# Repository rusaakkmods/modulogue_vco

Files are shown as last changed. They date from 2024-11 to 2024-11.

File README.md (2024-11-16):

### **Summary of Modular Synthesizer Project**

#### **Project Overview**
This modular synthesizer project involved designing and building multiple waveform generation and blending circuits, aimed at creating a versatile and adjustable synthesizer module. The primary goals were to implement various waveforms, include a noise source, and blend all the generated signals into a single output. The project also included specific modifications, such as fine-tuning, power supply design, and signal buffering to ensure stability and reliability.

#### **Key Components and Stages**

1. **Oscillator Core (Ramp Core)**
   - A ramp core oscillator was designed using a **TL072** operational amplifier as the integrator, along with a **2N3904** transistor and **CA3086** transistor array for current mirroring.
   - The integrator frequency is controlled by **RV1**, with an additional fine-tuning **trimmer (R36)**, allowing precise frequency adjustment.
   - **CD40106 Schmitt Trigger** inverters were used for signal buffering, ensuring the stability of the output signal.

2. **Waveform Generation and Blending**
   - The circuit generates several basic waveforms: **sawtooth, triangle, sine, and pulse**.
   - Each waveform output is blended with an adjustable amount of noise using **JFETs (2N5457)** as voltage-controlled amplifiers (VCAs).
   - The blend output of each waveform was further processed through a buffering stage using **TL072** operational amplifiers.

3. **Noise Source and Filtering**
   - A **white noise generator** was implemented using a **BC547** transistor, with the noise amplified by a **TL072** operational amplifier.
   - Adjustable filtering was added to shape the noise characteristics, providing both **high-pass** and **low-pass** controls, implemented with **RV7** and **RV6**.
   - The filtered noise was further buffered to ensure clean blending with the other waveforms.

4. **Signal Mixing**
   - The blended outputs of the sawtooth, triangle, sine, and pulse waveforms were mixed into a final output using a **TL072** operational amplifier configured as a summing amplifier.
   - **Mix Out** provides a composite audio signal with all waveforms mixed with noise, with individual blending for each waveform.

5. **Power Supply Design**
   - A **Eurorack power connector (J9)** was used for powering the module, providing **±12V, +5V, CV, and Gate** signals.
   - **Protection diodes (1N5819)** were added to each power line, followed by capacitors for decoupling and stability (±12V and +5V).
   - A **single power-on LED indicator** was added to the +5V line, indicating when the module is powered.

#### **Challenges and Improvements**
- **Thermal Coupling**: The **CA3086/3046** transistor array was used for better thermal coupling of the transistors, which helped reduce frequency drift and improved pitch stability.
- **Signal Buffering**: The use of **CD40106** Schmitt Trigger inverters for buffering was initially a concern due to their threshold nature. This was addressed by careful selection of the threshold voltage levels, ensuring proper signal integrity.
- **Component Selection**: The decision to use **TL072** for all operational amplifier needs was made due to its wide availability, cost-effectiveness, and adequate performance characteristics for audio signal processing.

#### **Outcome**
- A fully functional modular synthesizer module was designed, capable of generating sawtooth, triangle, sine, and pulse waveforms, each of which can be blended with an adjustable amount of noise.
- The project successfully addressed all the initial design goals, providing flexibility in waveform generation and blending, along with a stable power supply and efficient signal buffering.

This modular synthesizer is now ready for integration into a Eurorack system, providing unique sonic possibilities through its noise blending and waveform generation features.

### **Comprehensive Review of Synthesizer Schematics**

#### **Project Overview**
The goal of our project was to create a versatile analog synthesizer module capable of generating multiple waveform outputs, including sawtooth, triangle, sine, pulse, and noise. We also aimed for flexibility in signal blending, along with a reliable power section for consistent operation. The design uses commonly available components, ensuring it can be built with minimal specialized parts while providing a high level of functionality.

Below is a detailed review of the individual sections of the schematics, and how they align with our goals:

#### **1. Ramp Core Oscillator**
- **Schematic (01_ramp_core.png)**: The ramp core oscillator is at the heart of this synthesizer. It utilizes a **TL072 op-amp** to generate a stable ramp waveform, which serves as the basis for shaping other waveforms.
- **Components & Design Considerations**:
  - **CA3086/3046** transistor array forms a **current mirror**, which is key for controlling the ramp's linearity and stability.
  - **RV1 (100kΩ)** is used for frequency control, with **R36 (10kΩ)** added to ensure finer tuning.
  - The use of **Q2 (2N3904)** as a current sink and the **Schmitt trigger (CD40106)** for buffering ensures a sharp and well-defined ramp reset.
- **Conclusion**: This section effectively creates the ramp waveform with control over its frequency and reset characteristics. The fine-tuning and thermal coupling of transistors enhance pitch stability, meeting our goal of producing a precise core waveform.

#### **2. Triangle Wave Shaper**
- **Schematic (02_triangle_wave.png)**: The ramp waveform is shaped into a triangle wave using a **TL072** op-amp and a pair of **diodes (1N4148)**.
- **Symmetry Control**:
  - **RV4 (10kΩ)** allows for symmetry adjustments, ensuring a balanced triangle wave. Proper alignment of diodes helps achieve a linear slope on both halves of the triangle.
- **Conclusion**: The triangle wave is a fundamental waveform in many synthesis processes, and the use of a symmetry adjustment meets our goal of ensuring waveform accuracy.

#### **3. Sine Wave Shaper**
- **Schematic (03_sine_wave.png)**: The triangle waveform is converted into a sine wave through a feedback network using **capacitor C4** and **TL072**.
- **Shaping and Adjustment**:
  - The trimmer **RV2 (10kΩ)** is critical for reducing harmonic distortion and shaping the sine wave properly.
- **Conclusion**: The sine wave shaping circuit effectively smooths the triangle waveform, creating a sine with adjustable harmonic content. This fulfills our goal of generating a clean, adjustable sine output.

#### **4. Pulse Wave Shaper**
- **Schematic (04_pulse_wave.png)**: The **TL072 (U4B)** op-amp shapes the input from the triangle waveform and LFO into a pulse waveform.
- **Pulse Width Control**:
  - **RV5 (10kΩ)** allows manual control of the pulse width, while the **LFO** input modulates the pulse width, adding versatility for different modulation scenarios.
- **Conclusion**: The pulse width modulation capability, along with manual control, provides the desired flexibility in sound design, meeting our project objectives for waveform variety.

#### **5. Noise Generator**
- **Schematic (05_noise_generator_v2.png)**: Noise is generated using a **CA3086/3046 transistor** and amplified with a **TL072 (U5A)**.
- **Filtering**:
  - **RV7** and **RV8** are used to control the high-pass filter characteristics, allowing adjustments in the coloration of the noise output.
- **Conclusion**: Noise generation with adjustable filtering is useful for creating diverse sound textures, aligning well with our goal of a versatile noise section.

#### **6. Waveform Blending and Summing**
- **Schematic (06_mixed_out.png)**: Each waveform output is blended using a **summing amplifier (TL072, U10B)**.
- **Mixing Control**:
  - Equal resistances (**100kΩ**) for each input ensure that all waveforms are summed evenly, providing a balanced mixed output.
- **Conclusion**: This blending stage achieves the goal of providing a single output that contains a mix of all generated waveforms, offering a comprehensive signal suitable for various applications.

#### **7. Power Supply and Distribution**
- **Schematic (07_power_connector.png)**: The power section delivers **+12V, -12V, and +5V** to the different parts of the circuit.
- **Power Integrity**:
  - **Diodes (1N5819)** protect against reverse polarity, and capacitors ensure proper decoupling.
  - The addition of an LED indicator for the **+5V** line serves as a power-on visual indicator.
- **Conclusion**: The power section is robust, ensuring stable operation across the synthesizer. Proper decoupling and visual status indication align with the goal of reliability.

#### **8. Output Connections**
- **Schematic (08_outputs.png)**: Each generated waveform, including the mixed output, is connected to individual output jacks.
- **Labelling and Accessibility**:
  - Proper labeling of outputs ensures that each waveform can be accessed easily, making the synthesizer user-friendly.
- **Conclusion**: The output interface meets our objective of making all waveforms accessible for external use, fulfilling the goal of usability.

### **Overall Assessment**
The project successfully meets the outlined objectives:
- **Versatility**: The synthesizer offers a wide range of waveforms—sawtooth, triangle, sine, pulse, and noise—each with adjustable parameters, providing a rich palette for sound design.
- **Stability and Control**: The use of **thermal coupling**, **fine-tuning trimmers**, and **proper filtering** ensures the oscillator remains stable, while the power section guarantees reliable operation.
- **User-Friendly Design**: The interface, including labeled outputs and the power-on indicator, makes the synthesizer easy to operate.

Overall, the design is well-executed, with each section effectively contributing to the synthesizer's versatility and reliability. The schematics illustrate a thoughtful and methodical approach to achieving a high-quality analog synthesizer module.

#### **Complete Bill of Materials (BOM)**

| No | Reference | Value | Qty |
| -- | --- | --- | --- |
| 1  | C1 | 22nF | 1 |
| 2  | C2, C3, C5, C6, C10, C11, C12, C17, C18, C19, C20, C21, C22, C23, C24, C25, C26, C27, C28, C29, C32 | 100nF | 21  |
| 3  | C4, C7 | 10pF ~ 33pF | 2 |
| 4  | C8, C13, C14, C15, C16 | 10uF | 5 |
| 5  | C9 | 10nF | 1 |
| 6  | C30, C31, C33 | 47uF | 3 |
| 7  | D1, D2 | 1N4148 | 2 |
| 8  | D3, D4, D5, D6 | 1N4148 | 4 |
| 9  | D7, D8, D9 | 1N5819 | 3 |
| 10 | D10 | POWER ON | 1 |
| 11 | J1 | SAWTOOTH | 1 |
| 12 | J2 | TRIANGLE | 1 |
| 13 | J3 | SINE | 1 |
| 14 | J4 | PULSE | 1 |
| 15 | J5 | MIX OUT | 1 |
| 16 | J6 | NOISE | 1 |
| 17 | J7 | HP NOISE | 1 |
| 18 | J9 | POWER | 1 |
| 19 | J10 | CV IN | 1 |
| 20 | Q2 | 2N3904 | 1 |
| 21 | Q3, Q4, Q5, Q6 | 2N5457 | 4 |
| 22 | R1, R15, R20, R21, R22, R23, R24, R25, R26, R27, R28, R29, R30, R31, R32, R33, R34, RV1 | 100K | 18  |
| 23 | R2, R6, R9, R10, R11, R12, R18, R19, R36, RV2, RV4, RV5 | 10K | 12  |
| 24 | R3, R4, R5, R7, R8, R13, R35 | 1K | 7 |
| 25 | R14, R16 | 1M | 2 |
| 26 | R17 | 470K | 1 |
| 27 | RV3, RV6, RV7, RV8 | 50K | 4 |
| 28 | U1, U4, U5, U6, U7, U8, U9, U10 | TL072 | 8 |
| 29 | U2 | CD40106 | 1 |
| 30 | U3 | CA3086/3046 | 1 |

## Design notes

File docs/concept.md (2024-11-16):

Here's a complete schematic and routing guide for your VCO module, using the **CA3086** transistor array. This design includes **sawtooth, triangle, sine, pulse, and noise** waveforms, along with an updated **Bill of Materials (BOM)**. I'll provide a clear description of each section, as well as connections to guide you through the process.

### **Schematic Overview**

The VCO is divided into the following stages:

1. **Sawtooth Core Oscillator (Ramp Core) with CA3086**
2. **Triangle Wave Shaper**
3. **Sine Wave Shaper**
4. **Pulse Wave with PWM Control**
5. **Noise Generator**

#### **1. Sawtooth Core Oscillator (Ramp Core with CA3086)**

**Components**:
- **Op-Amp (U1)**: TL072 or LM13700 for the integrator.
- **Capacitor (C1)**: 22nF to 100nF (sets frequency range).
- **Resistor (R1)**: 100kΩ.
- **Transistor Array (Q1, Q2 - CA3086)**: Used for the exponential converter.
- **Schmitt Trigger (IC1)**: CD40106 for reset control.
- **NPN Transistor (Q3 - Reset)**: 2N3904.
- **Current Limiting Resistor (R2)**: 10kΩ.
- **Frequency Control Potentiometer (VR2)**: 100kΩ for manual frequency adjustment.

**Connections**:
- **Integrator Op-Amp (U1)**:
  - **Inverting Input (-)**: Connect **R1** (100kΩ) between the **inverting input** and the **collector of Q1** (CA3086).
  - **Non-Inverting Input (+)**: Connect to **ground**.
  - **Capacitor C1**: Connect between the **output of U1** and the **inverting input (-)**.
  - **Frequency Control Potentiometer (VR2)**: Connect one end of **VR2** to **ground** and the other end to the **junction of C1 and U1**. The wiper of **VR2** should connect to the **inverting input** of **U1**. Adjusting **VR2** will change the effective resistance in the circuit, allowing you to control the oscillator frequency.
- **CA3086 Transistor Array**:
  - **Base of Q1**: Connect to the **1V/octave CV input**.
  - **Emitters of Q1 and Q2**: Tie together and connect to **ground** via a **small resistor (R3 - 1kΩ)**.
  - **Collector of Q1**: Connect to **R1**, which then goes to **U1** inverting input.
- **Schmitt Trigger (IC1 - CD40106)**:
  - **Input (Pin 1)**: Connect to the **output of U1** (sawtooth waveform).
  - **Output (Pin 2)**: Connect to the **base of Q3** via a **current-limiting resistor (R2 - 10kΩ)**.
- **Reset Transistor (Q3 - 2N3904)**:
  - **Collector**: Connect to the **junction of C1 and U1**.
  - **Emitter**: Connect to **ground**.

#### **2. Triangle Wave Shaper**

**Components**:
- **Op-Amp (U2)**: TL072.
- **Resistor Divider (R4, R5)**: 10kΩ each to adjust symmetry.

**Connections**:
- **Sawtooth Output to Triangle Shaper**:
  - Connect the **sawtooth output from U1** to the **inverting input of U2** through **R4** (10kΩ).
  - **Non-Inverting Input** of **U2** should be connected to **ground**.
- **Triangle Wave Output**:
  - The **output of U2** will generate a **triangle wave** by inverting and folding the sawtooth.

#### **3. Sine Wave Shaper**

**Components**:
- **Op-Amp (U3)**: TL072.
- **Diodes (D1, D2)**: 1N4148 for wave shaping.

**Connections**:
- **Triangle Wave Input**:
  - Feed the **triangle wave output from U2** to the **input of U3**.
- **Shaper Circuit**:
  - Connect **D1 and D2** across the **feedback path** of **U3** to round the triangle wave into a sine.
- **Sine Wave Output**:
  - The **output of U3** will be the **sine wave**.

#### **4. Pulse Wave with PWM Control**

**Components**:
- **Schmitt Trigger (IC1 - Gate 2)**: CD40106.
- **PWM Control Potentiometer (VR1)**: 100kΩ.

**Connections**:
- **Sawtooth to Schmitt Trigger**:
  - Connect the **sawtooth output** from **U1** to the **input of another gate on IC1** (e.g., Pin 3).
- **PWM Control**:
  - Use **VR1** to provide an adjustable **threshold voltage** to the **input of the Schmitt Trigger**.
- **Pulse Wave Output**:
  - The **output of the Schmitt Trigger gate** will provide the **pulse wave** with adjustable PWM.

#### **5. Noise Generator**

**Components**:
- **NPN Transistor (Q4)**: 2N3904 for noise generation.
- **Amplifier Op-Amp (U4)**: TL072.
- **Collector Resistor (R6)**: 100kΩ.
- **Capacitor (C2)**: 100nF for noise filtering.

**Connections**:
- **Noise Source**:
  - Use **Q4** with its **collector-base junction reverse biased** to generate **white noise**.
- **Amplification**:
  - Feed the **noise output from Q4** to **U4** configured as an amplifier.
  - The **output of U4** will be the **noise signal**.

### **Bill of Materials (BOM)**

| Part Description | Reference | Value | Suggested Part Number  | Quantity |
|---|---|---|---|---|
| Op-Amp | U1, U2, U3, U4 | TL072 | TL072CN | 4 |
| Capacitor (Integrator) | C1 | 22nF | Ceramic or Film | 1 |
| Resistor (Integrator) | R1 | 100kΩ | 1/4W, 1% Tolerance | 1 |
| Transistor Array | Q1, Q2 | CA3086 | CA3086 | 1 |
| Small Resistor (Thermal Stability) | R3 | 1kΩ | 1/4W, 1% Tolerance | 1 |
| Schmitt Trigger | IC1 | CD40106 | CD40106BE | 1 |
| NPN Transistor (Reset) | Q3 | 2N3904 | 2N3904 | 1 |
| Current Limiting Resistor  | R2 | 10kΩ | 1/4W, 1% Tolerance | 1 |
| Resistor Divider | R4, R5 | 10kΩ each | 1/4W, 1% Tolerance | 2 |
| Diodes for Sine Shaper | D1, D2 | 1N4148 | 1N4148 | 2 |
| Potentiometer (PWM Control)| VR1 | 100kΩ | Linear Taper | 1 |
| Potentiometer (Frequency Control) | VR2 | 100kΩ | Linear Taper | 1 |
| NPN Transistor (Noise Source) | Q4 | 2N3904 | 2N3904 | 1 |
| Resistor (Collector Resistor) | R6 | 100kΩ | 1/4W, 1% Tolerance | 1 |
| Capacitor (Noise Filtering)| C2 | 100nF | Ceramic | 1 |
| Decoupling Capacitors | C3, C4, C5  | 100nF | Ceramic | 3 |

### **Power Supply and Layout Tips**
- **Power Supply**: Use the **Eurorack standard power supply** of **±12V** for proper operation of op-amps and CD40106.
- **Decoupling**: Place **100nF capacitors** near each IC's power pins to reduce noise.
- **Grounding**: Use **star grounding** to avoid ground loops.
- **Thermal Considerations**: Place **CA3086** transistors close together for consistent thermal tracking.

### **Summary**
This design uses the **CA3086** transistor array for improved matching and thermal stability, making it an excellent choice for your VCO project. The guide includes all necessary components, connections, and routing tips to create a reliable and stable oscillator for your modular synthesizer.

### **Alternatives to CA3086 Transistor Array**

If you're looking for alternatives to the **CA3086** transistor array for use in applications like exponential converters in synthesizer circuits, here are some viable options:

#### **1. LM3046**
- **LM3046** is a direct replacement for the **CA3086**. It also contains **five NPN transistors** in a single package.
- It features **similar specifications** and offers excellent **matching** and **thermal tracking**, making it a drop-in alternative.

#### **2. CA3046**
- **CA3046** is another option that contains **five NPN transistors** like the **CA3086**.
- This array offers **matched transistors** suitable for differential pairs and analog applications where thermal tracking is crucial.

#### **3. MAT12 (Analog Devices)**
- The **MAT12** is a **dual NPN matched transistor** from **Analog Devices**, designed for precision analog circuits.
- It provides **excellent thermal matching**, much better than discrete transistors, making it a suitable but more expensive alternative.
- The **MAT12** is known for its **low noise** and **excellent gain matching**, making it ideal for high-performance VCO designs.

#### **4. SSM2212**
- **SSM2212** is another **dual matched NPN transistor** designed for precision.
- Manufactured by **Analog Devices**, this component is well-suited for **exponential converters** due to its **closely matched gain** and **temperature coefficient**.

#### **5. Discrete Matched Transistor Pairs (e.g., BC547)**
- Another approach is to manually match **discrete transistors** like **BC547**.
- This requires careful measurement to ensure similar **gain (HFE)** and **base-emitter voltage (V_BE)**.
- While this method is more time-consuming, it is cost-effective if the **CA3086** or similar arrays are not readily available.

#### **6. THAT300 (THAT Corporation)**
- The **THAT300** is a **quad NPN transistor array** specifically designed for analog precision applications.
- It has **four transistors** that are matched and thermally coupled on the same die.
- This component provides excellent **matching** and is often used in high-end analog synthesizer designs.

### **Summary of Alternatives**
- **Direct Replacements**: **LM3046**, **CA3046**.
- **High Precision**: **MAT12**, **SSM2212**, **THAT300**.
- **Cost-Effective Option**: **Manually matched discrete transistors** like **BC547**.

The best alternative will depend on your specific requirements—if you're looking for cost-effectiveness, manually matched **BC547** transistors may be suitable, while the **LM3046** or **CA3046** can be direct substitutes with similar characteristics to the **CA3086**. For higher precision, **MAT12** or **THAT300** would be ideal, especially in designs where temperature stability and minimal drift are critical.

### **CA3086 vs CA3046**

The **CA3086** and **CA3046** are both transistor arrays containing **five NPN transistors** and are commonly used in analog applications where matched transistors are required. Here is a comparison to help you understand the differences and similarities between the two:

#### **Similarities**
1. **Transistor Count**: Both **CA3086** and **CA3046** contain **five NPN transistors** on a single chip.
2. **Monolithic Design**: The transistors are fabricated on the same die, ensuring good **matching** and **thermal tracking**.
3. **Application Use**: Both can be used in **exponential converters**, **differential pairs**, or other analog circuits where matched transistors are required.
4. **Pin Configuration**: The **pinout** of the CA3086 and CA3046 is identical, making them interchangeable in most circuit designs.

#### **Differences**
1. **Voltage Ratings**:
   - The **CA3046** has a higher **collector-emitter voltage rating** compared to the **CA3086**.
   - **CA3046** can handle a **maximum collector-emitter voltage (V_CE)** of **20V**, while **CA3086** typically has a lower voltage rating of **15V**.
2. **Temperature Range**:
   - The **CA3046** is rated for **wider temperature ranges**, making it more suitable for industrial applications where the operating environment may be harsher.
   - The **CA3086** is more commonly used in consumer electronics or in environments with more controlled temperatures.
3. **Availability**:
   - The **CA3046** is generally easier to find compared to the **CA3086**, which might be less available in the market due to its older technology.

#### **Which One to Use?**
- **CA3086**: Suitable for projects where **voltage ratings** are not a concern, and operating in typical room temperature conditions. It is a good option for hobbyist projects or legacy circuits where the **CA3086** was originally used.
- **CA3046**: Recommended for designs that require **higher voltage ratings** or need to operate in **wider temperature ranges**. It is a more robust option for applications where reliability over a range of conditions is critical.

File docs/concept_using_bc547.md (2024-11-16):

Here's a complete schematic and routing guide for your VCO module, using **matched BC547 transistors** instead of the **CA3086** transistor array. This design includes **sawtooth, triangle, sine, pulse, and noise** waveforms, along with an updated **Bill of Materials (BOM)**. I'll provide a clear description of each section, as well as connections to guide you through the process.

### **Schematic Overview**

The VCO is divided into the following stages:

1. **Sawtooth Core Oscillator (Ramp Core with Matched BC547 Transistors)**
2. **Triangle Wave Shaper**
3. **Sine Wave Shaper**
4. **Pulse Wave with PWM Control**
5. **Noise Generator**

#### **1. Sawtooth Core Oscillator (Ramp Core with Matched BC547 Transistors)**

**Components**:
- **Op-Amp (U1)**: TL072 or LM13700 for the integrator.
- **Capacitor (C1)**: 22nF to 100nF (sets frequency range).
- **Resistor (R1)**: 100kΩ.
- **Matched Transistors (Q1, Q2 - BC547)**: Used for the exponential converter.
- **Schmitt Trigger (IC1)**: CD40106 for reset control.
- **NPN Transistor (Q3 - Reset)**: 2N3904.
- **Current Limiting Resistor (R2)**: 10kΩ.
- **Frequency Control Potentiometer (VR2)**: 100kΩ for manual frequency adjustment.

**Connections**:
- **Integrator Op-Amp (U1)**:
  - **Inverting Input (-)**: Connect **R1** (100kΩ) between the **inverting input** and the **collector of Q1** (BC547).
  - **Non-Inverting Input (+)**: Connect to **ground**.
  - **Capacitor C1**: Connect between the **output of U1** and the **inverting input (-)**.
  - **Frequency Control Potentiometer (VR2)**: Connect one end of **VR2** to **ground** and the other end to the **junction of C1 and U1**. The wiper of **VR2** should connect to the **inverting input** of **U1**. Adjusting **VR2** will change the effective resistance in the circuit, allowing you to control the oscillator frequency.
- **Matched Transistors (Q1, Q2 - BC547)**:
  - **Base of Q1**: Connect to the **1V/octave CV input**.
  - **Emitters of Q1 and Q2**: Tie together and connect to **ground** via a **small resistor (R3 - 1kΩ)**.
  - **Collector of Q1**: Connect to **R1**, which then goes to **U1** inverting input.
- **Schmitt Trigger (IC1 - CD40106)**:
  - **Input (Pin 1)**: Connect to the **output of U1** (sawtooth waveform).
  - **Output (Pin 2)**: Connect to the **base of Q3** via a **current-limiting resistor (R2 - 10kΩ)**.
- **Reset Transistor (Q3 - 2N3904)**:
  - **Collector**: Connect to the **junction of C1 and U1**.
  - **Emitter**: Connect to **ground**.

#### **2. Triangle Wave Shaper**

**Components**:
- **Op-Amp (U2)**: TL072.
- **Resistor Divider (R4, R5)**: 10kΩ each to adjust symmetry.

**Connections**:
- **Sawtooth Output to Triangle Shaper**:
  - Connect the **sawtooth output from U1** to the **inverting input of U2** through **R4** (10kΩ).
  - **Non-Inverting Input** of **U2** should be connected to **ground**.
- **Triangle Wave Output**:
  - The **output of U2** will generate a **triangle wave** by inverting and folding the sawtooth.

#### **3. Sine Wave Shaper**

**Components**:
- **Op-Amp (U3)**: TL072.
- **Diodes (D1, D2)**: 1N4148 for wave shaping.

**Connections**:
- **Triangle Wave Input**:
  - Feed the **triangle wave output from U2** to the **input of U3**.
- **Shaper Circuit**:
  - Connect **D1 and D2** across the **feedback path** of **U3** to round the triangle wave into a sine.
- **Sine Wave Output**:
  - The **output of U3** will be the **sine wave**.

#### **4. Pulse Wave with PWM Control**

**Components**:
- **Schmitt Trigger (IC1 - Gate 2)**: CD40106.
- **PWM Control Potentiometer (VR1)**: 100kΩ.

**Connections**:
- **Sawtooth to Schmitt Trigger**:
  - Connect the **sawtooth output** from **U1** to the **input of another gate on IC1** (e.g., Pin 3).
- **PWM Control**:
  - Use **VR1** to provide an adjustable **threshold voltage** to the **input of the Schmitt Trigger**.
- **Pulse Wave Output**:
  - The **output of the Schmitt Trigger gate** will provide the **pulse wave** with adjustable PWM.

#### **5. Noise Generator**

**Components**:
- **NPN Transistor (Q4)**: 2N3904 for noise generation.
- **Amplifier Op-Amp (U4)**: TL072.
- **Collector Resistor (R6)**: 100kΩ.
- **Capacitor (C2)**: 100nF for noise filtering.

**Connections**:
- **Noise Source**:
  - Use **Q4** with its **collector-base junction reverse biased** to generate **white noise**.
- **Amplification**:
  - Feed the **noise output from Q4** to **U4** configured as an amplifier.
  - The **output of U4** will be the **noise signal**.

### **Bill of Materials (BOM)**

| Part Description | Reference | Value | Suggested Part Number  | Quantity |
|---|---|---|---|---|
| Op-Amp | U1, U2, U3, U4 | TL072 | TL072CN | 4 |
| Capacitor (Integrator) | C1 | 22nF | Ceramic or Film | 1 |
| Resistor (Integrator) | R1 | 100kΩ | 1/4W, 1% Tolerance | 1 |
| Matched Transistors | Q1, Q2 | BC547 | Hand-matched BC547 | 2 |
| Small Resistor (Thermal Stability) | R3 | 1kΩ | 1/4W, 1% Tolerance | 1 |
| Schmitt Trigger | IC1 | CD40106 | CD40106BE | 1 |
| NPN Transistor (Reset) | Q3 | 2N3904 | 2N3904 | 1 |
| Current Limiting Resistor  | R2 | 10kΩ | 1/4W, 1% Tolerance | 1 |
| Resistor Divider | R4, R5 | 10kΩ each | 1/4W, 1% Tolerance | 2 |
| Diodes for Sine Shaper | D1, D2 | 1N4148 | 1N4148 | 2 |
| Potentiometer (PWM Control)| VR1 | 100kΩ | Linear Taper | 1 |
| Potentiometer (Frequency Control) | VR2 | 100kΩ | Linear Taper | 1 |
| NPN Transistor (Noise Source) | Q4 | 2N3904 | 2N3904 | 1 |
| Resistor (Collector Resistor) | R6 | 100kΩ | 1/4W, 1% Tolerance | 1 |
| Capacitor (Noise Filtering)| C2 | 100nF | Ceramic | 1 |
| Decoupling Capacitors | C3, C4, C5  | 100nF | Ceramic | 3 |

### **Power Supply and Layout Tips**
- **Power Supply**: Use the **Eurorack standard power supply** of **±12V** for proper operation of op-amps and CD40106.
- **Decoupling**: Place **100nF capacitors** near each IC's power pins to reduce noise.
- **Grounding**: Use **star grounding** to avoid ground loops.
- **Thermal Considerations**: Place **Q1 and Q2** (BC547) close together and consider using thermal compound or adhesive to improve thermal tracking.

### **Summary**
This design uses **matched BC547 transistors** for the exponential converter instead of the **CA3086** array. Careful matching of the transistors is important to achieve good temperature stability. The guide includes all necessary components, connections, and routing tips to create a reliable and stable oscillator for your modular synthesizer.

### **Guide to Manual Matching of Transistors**

Manual matching of transistors is an important process for circuits like **exponential converters** in VCOs, where precise performance and temperature stability are crucial. Here's a step-by-step guide to manually match transistors, particularly for **BC547** transistors.

#### **Goal of Matching Transistors**
For circuits like **exponential converters** in a VCO, it is important to match transistors for the following characteristics:
1. **Current Gain (HFE)** - The ratio of collector current to base current.
2. **Base-Emitter Voltage (V_BE)** - The voltage drop from base to emitter when conducting.

Closely matching these parameters helps improve the **accuracy** and **temperature stability** of your circuit.

#### **Equipment Needed**
1. **Multimeter with HFE Measurement** (preferable).
2. **Breadboard and Power Supply** (optional if you prefer building a test circuit).
3. **Test Circuit Components** - Resistors, battery, wires (optional if you need to measure with a test setup).

#### **Step-by-Step Guide to Manually Match Transistors**

##### **Method 1: Using a Multimeter with HFE Measurement**

1. **Set the Multimeter to HFE Mode**:
   - Most multimeters have a setting for measuring the **HFE** of transistors. Set your multimeter to this mode.

2. **Identify the Pins**:
   - The **BC547** is a standard NPN transistor with the pinout: **Collector (C)**, **Base (B)**, **Emitter (E)**.
   - Identify these pins on the transistor using the datasheet or reference image (typically, if looking at the flat face of the transistor, from left to right: **C**, **B**, **E**).

3. **Insert the Transistor**:
   - Insert the **collector, base, and emitter** pins of the transistor into the corresponding slots in the **HFE socket** of the multimeter (often labeled for NPN and PNP transistors).

4. **Record the HFE Value**:
   - Read the **HFE** value displayed on the multimeter and note it down.
   - Repeat this process for all the transistors you want to match, and write down each **HFE** value.

5. **Match Transistors**:
   - Compare the **HFE values** of all the transistors.
   - Find two transistors that have nearly identical **HFE values**. Ideally, they should be within **5%** of each other for good matching in a VCO application.

##### **Method 2: Using a Test Circuit on a Breadboard**

If your multimeter does not have an **HFE measurement mode**, you can use a simple test circuit to measure **V_BE** and **HFE**.

1. **Test Circuit Setup**:
   - Use a **breadboard** to set up a simple circuit to measure **HFE** and **V_BE**.
   - You’ll need:
     - **Power Supply** (e.g., a **9V battery** or a **DC power supply** set to 9-12V).
     - **Resistor** (1kΩ and 10kΩ).

2. **Circuit Description**:
   - Connect a **1kΩ resistor** between the **base** and the **positive supply**.
   - Connect a **10kΩ resistor** between the **collector** and the **positive supply**.
   - Connect the **emitter** to **ground**.

3. **Measure Collector Current (I_C)**:
   - Measure the **voltage across the 10kΩ collector resistor** using the multimeter.
   - **Calculate the collector current (I_C)** using **Ohm’s Law**: \( I_C = 
rac{V_R}{R} \), where \( V_R \) is the voltage across the resistor and \( R \) is the resistor value (10kΩ).
   
4. **Calculate Base Current (I_B)**:
   - Measure the **voltage across the 1kΩ base resistor**.
   - **Calculate the base current (I_B)** similarly: \( I_B = 
rac{V_R}{R} \), where \( V_R \) is the voltage across the 1kΩ resistor.

5. **Calculate HFE**:
   - Use the formula: \( HFE = 
rac{I_C}{I_B} \).
   - Record this value for each transistor.

6. **Measure V_BE**:
   - Measure the **voltage drop between the base and emitter (V_BE)**.
   - Note that **V_BE** should ideally be close, preferably within **5mV** for well-matched transistors.

7. **Select Matched Pairs**:
   - Compare the **HFE** values and **V_BE** values of all transistors.
   - Select transistors that have similar **HFE** and **V_BE** values.

#### **Tips for Manual Matching**

1. **Thermal Matching**:
   - Perform measurements under consistent temperature conditions. Small changes in temperature can affect **HFE** and **V_BE** significantly.
   - If possible, keep the transistors close together or even attach them with a thermally conductive adhesive when assembling the final circuit to minimize differences due to temperature variations.

2. **Batch Measurement**:
   - It’s a good idea to buy more transistors than needed and measure them all to find the closest match.
   - Transistors from the **same batch** are more likely to have similar characteristics due to the consistency of manufacturing.

3. **Target Matching Accuracy**:
   - For most analog synthesizer VCO applications, aim for **matching within 5%** for **HFE** and **within 5-10mV** for **V_BE**.
   - Better matching will result in **more accurate pitch tracking** and **less drift** with temperature changes.

#### **Summary**
- Use a **multimeter with HFE measurement** if available—this is the easiest and quickest way to match transistors.
- Alternatively, build a **test circuit** to measure **HFE** and **V_BE** if a dedicated HFE meter is not available.
- Look for **matched HFE and V_BE** values to ensure stability, especially for the **exponential converter** stage in a **VCO**.

Using well-matched transistors will provide the **temperature stability** and **precision** necessary for reliable musical tuning and pitch tracking in your synthesizer project.

### **Methods to Improve Thermal Tracking for BC547 Transistors**

Thermal tracking is critical in circuits like **exponential converters** used in **VCOs** to ensure consistent performance and minimal pitch drift. For **BC547 transistors**, here are effective methods to improve thermal tracking:

#### **1. Thermal Adhesive Compound**
- Apply a **thermal adhesive compound** between the two matched transistors (e.g., **Q1 and Q2** in your VCO circuit).
- This ensures that both transistors are in **direct thermal contact**, allowing them to heat up and cool down at the same rate.
- By maintaining a similar temperature, the **gain (HFE)** and **V_BE** remain more consistent, improving stability.

#### **2. Heat Shrink Tubing**
- Use a piece of **heat shrink tubing** to encase both transistors together.
- This method holds the transistors in tight physical contact, improving thermal equilibrium between them.
- The heat shrink tubing helps them share heat effectively, reducing any thermal gradient that might cause drift.

#### **3. Copper Foil or Heatsink**
- Wrap both transistors with **copper foil tape** to increase their thermal conductivity.
- Copper is highly thermally conductive, and wrapping it around the transistors will help distribute heat evenly between them.
- Alternatively, use a small **metal heatsink** that is in contact with both transistors to stabilize their temperature.

#### **4. Mounting on the Same PCB Pad**
- Place both transistors on the same **thermal pad** or closely spaced **PCB area**.
- The shared **copper pad** helps to maintain an even temperature between the transistors, as it acts as a heat spreader.
- Make sure to avoid excessive spacing between the transistors, as proximity is key for effective thermal coupling.

#### **Summary**
- **Thermal Adhesive Compound** and **heat shrink tubing** are the simplest methods for improving thermal tracking of **BC547 transistors**.
- Using **copper foil tape** or a **heatsink** further enhances thermal contact and helps maintain temperature consistency.
- **PCB layout considerations**, such as mounting both transistors on the same pad, also play a crucial role in ensuring they track each other's temperature closely.

These methods will help minimize temperature-induced variations in the **exponential converter** circuit, leading to improved stability and pitch accuracy for your VCO.

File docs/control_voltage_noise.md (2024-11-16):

### **Voltage-Controlled Noise Blending Using Waveform Signal**

You can achieve voltage-controlled noise blending by using the waveform signal itself to dynamically control the noise level. This approach creates a more dynamic and interesting effect, where the noise level changes in sync with the generated waveform, resulting in unique sonic characteristics.

#### **Solution Overview**

1. **Using Waveform Voltage as Control Signal**:
   - You can use the voltage from each waveform output (sawtooth, triangle, sine, pulse) to control the amplitude of the noise through a **Voltage-Controlled Amplifier (VCA)** or other modulation mechanisms.
   - The waveform acts as the **modulation source**, and the noise level changes accordingly with the waveform's voltage.

2. **Implementation Using VCA**:
   - Use a **Voltage-Controlled Amplifier (VCA)** to adjust the amplitude of the noise signal based on the waveform voltage.
   - The VCA will allow the noise level to be controlled dynamically. When the waveform voltage is high, the noise level will be high; when the waveform voltage is low, the noise level will decrease.

3. **Using a JFET (2N5457) as a VCA**:
   - A **JFET (2N5457)** can be used as a variable resistor in a VCA configuration.
   - Connect the noise signal to the **drain** of the JFET, and use the **gate** to receive the waveform voltage. This will control the effective resistance and hence modulate the noise output level.

4. **Envelope Follower Approach**:
   - Another way to control the noise level is to use an **envelope follower** to generate a control voltage from the waveform. The control voltage can then be used to drive a VCA or other modulation elements.
   - This approach allows for a more stable, smoothed-out control over the noise level, based on the overall amplitude of the waveform.

#### **Step-by-Step Implementation**

1. **Waveform as Control Signal**:
   - Take the output from each waveform generator (sawtooth, triangle, sine, pulse).
   - Use a **diode and capacitor** to create an **envelope follower**, which generates a control voltage proportional to the waveform amplitude.

2. **VCA for Noise Control**:
   - Use a **JFET-based VCA (2N5457)** to control the amplitude of the noise signal.
   - Connect the noise signal to the **drain** of the JFET, and the **source** to the output. The **gate** will receive the control voltage derived from the waveform, modulating the effective resistance of the JFET.

3. **Summing the Blended Output**:
   - After controlling the noise amplitude, use the existing **op-amp summing mixer** configuration to blend the noise signal into the respective waveform output.
   - This ensures that the final output contains the waveform with the dynamically controlled noise level.

#### **Advantages of Voltage-Controlled Noise Blending**

1. **Dynamic Noise Control**: The noise level changes dynamically based on the waveform amplitude, creating interesting sound effects and adding a dynamic layer to the synthesis.
2. **Unique Modulation Effects**: Different waveforms can be used to modulate the noise, resulting in unique noise effects that change with the waveform's shape and frequency.
3. **Simpler Implementation**: Using a JFET (2N5457) as a VCA provides a relatively simple and cost-effective method for achieving voltage-controlled noise modulation.

#### **Considerations**

- **Complexity**: Adding VCAs or using a JFET introduces more components and complexity to the circuit, but it provides significant control over the noise level.
- **Level Scaling**: The waveform voltage should be properly scaled to match the control requirements of the VCA or JFET. This may require additional circuitry, such as **op-amp buffers** or **level shifters**.

#### **Bill of Materials (BOM) Update**

| Part Description | Reference | Value | Suggested Part Number | Quantity |
|---|---|---|---|---|
| JFET | Q2 | 2N5457 | 2N5457 | 4 |
| Diode for Envelope Follower | D1, D2, D3, D4  | 1N4148 | 1N4148 | 4 |
| Capacitor for Envelope Follower | C14, C15, C16, C17 | 10μF | Electrolytic | 4 |
| Resistors for VCA | R26, R27, R28, R29 | 100kΩ | 1/4W, 1% Tolerance | 4 |
| Summing Op-Amp | U7A, U7B | TL072 | TL072CN | 2 |

This BOM update includes additional components for implementing voltage-controlled noise blending, including JFETs (2N5457) for the VCAs, diodes, and capacitors for the envelope follower, as well as additional resistors. Let me know if you need further clarification or additional assistance!

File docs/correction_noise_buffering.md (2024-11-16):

### **Detailed Schematic Routing for Noise Buffering Using TL072 and Waveform Mixing**

#### **Noise Buffering Using TL072**

1. **Buffered Noise Amplification**:
   - Start with the **filtered noise signal** output from the **filtered noise amplification stage**. This output comes from **pin 7** of **U5B (TL072)**.

2. **Connect to Buffer Op-Amp**:
   - Connect the output from **U5B (pin 7)** to the **non-inverting input (+)** of the buffer op-amp, which is **U6A (TL072)**.
   - Use a direct wire to connect **U5B (pin 7)** to **U6A (pin 3)**. This connection carries the filtered noise signal into the next op-amp stage.

3. **Voltage Follower Configuration**:
   - To configure **U6A (TL072)** as a **voltage follower**:
     - Connect the **output of U6A (pin 1)** directly to its **inverting input (-)**, which is **pin 2**.
     - This is done using a short wire to create a direct feedback loop, ensuring the op-amp operates as a unity gain buffer.
   - In this configuration, the output follows the input exactly, maintaining the analog characteristics of the signal.

4. **Buffered Noise Output**:
   - The buffered noise output is now taken from **pin 1** of **U6A**.
   - This output can be routed to the next stages, such as the **JFET-based VCAs** that blend the noise with the various waveforms.

5. **Power Connections**:
   - **VCC (+12V)**: Connect **pin 8** of **U6A** to **+12V**.
   - **VEE (-12V)**: Connect **pin 4** of **U6A** to **-12V**.
   - Ensure you have appropriate decoupling capacitors (e.g., **100nF**) between the power pins and ground to stabilize the power supply.

#### **Detailed Schematic Routing for Each Waveform**

1. **Waveform Outputs**:
   - Each waveform (SAW, TRI, SINE, PULSE) is generated by its respective oscillator circuitry and routed to the envelope follower for each waveform.

2. **Envelope Follower Configuration**:
   - **Diode and Capacitor Setup**:
     - Connect each waveform output to a **diode (1N4148)** followed by a **capacitor (10μF)** to create a control voltage that represents the envelope of each waveform.
     - The diode allows only the positive part of the signal to pass, and the capacitor smooths this signal to create a DC voltage proportional to the waveform amplitude.

3. **JFET-Based VCA Configuration**:
   - **JFET Selection**: Use **2N5457** JFETs (Q3, Q4, Q5, Q6) for each waveform.
   - **Drain Connection**: Connect the **drain** of each JFET to the **buffered noise output** from the **TL072 buffer stage (U6A, pin 1)**.
   - **Gate Connection**: Connect the **gate** of each JFET to the control voltage from the corresponding envelope follower.
     - Use a **series resistor (100kΩ)** for each gate connection to control the sensitivity.
   - **Source Connection**: Connect the **source** of each JFET to the **mixing resistor** before entering the summing op-amp.

4. **Summing Mixer Stage**:
   - **Op-Amp Selection**: Use **U6B, U7A, U7B, U8A (TL072)** for each waveform summing mixer.
   - **Mixing Resistor**: Connect each waveform output to a **mixing resistor (R21, R22, R23, R24 - 100kΩ)** before routing it to the **non-inverting input (+)** of the op-amp.
   - **Noise Input**: The noise signal controlled by the JFET is connected through another **mixing resistor (100kΩ)** to the **inverting input (-)** of the op-amp.
   - **Feedback Resistor**: Use a **feedback resistor (R26, R27, R28, R29 - 100kΩ)** to set the gain for each summing mixer stage.

5. **Power Connections for Summing Op-Amps**:
   - Connect **VCC (+12V)** to **pin 8** of each TL072.
   - Connect **VEE (-12V)** to **pin 4** of each TL072.
   - Place **decoupling capacitors (100nF)** close to the power pins to stabilize the power supply.

#### **Bill of Materials (BOM)**

| Part Description | Reference | Value | Suggested Part Number | Quantity |
|---|---|---|---|---|
| Buffered Noise Amplifier Op-Amp | U6A | TL072 | TL072CN | 1 |
| JFET for VCA | Q3, Q4, Q5, Q6  | 2N5457 | 2N5457 | 4 |
| Envelope Diodes | D1, D2, D3, D4  | 1N4148 | 1N4148 | 4 |
| Envelope Capacitors | C14, C15, C16, C17 | 10μF | Electrolytic | 4 |
| Mixing Resistors | R21, R22, R23, R24 | 100kΩ | 1/4W, 1% Tolerance | 4 |
| Feedback Resistors | R26, R27, R28, R29 | 100kΩ | 1/4W, 1% Tolerance | 4 |
| Summing Mixer Op-Amps | U6B, U7A, U7B, U8A | TL072 | TL072CN | 4 |
| Decoupling Capacitors | C18, C19, C20, C21, C22 | 100nF | Ceramic | 5 |
| Gate Resistors for JFETs | R30, R31, R32, R33 | 100kΩ | 1/4W, 1% Tolerance | 4 |

This detailed schematic routing guide includes the noise buffering and the mixing stages for each waveform, ensuring that the analog noise is properly buffered and blended with the waveform signals. Let me know if you need more clarification on any part of the routing or the BOM.

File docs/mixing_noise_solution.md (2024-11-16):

### **Utilizing CD40106 for Independent Noise Blending with Each Waveform**

To achieve independent noise blending with each waveform output (sawtooth, triangle, sine, pulse), the remaining 5 op-amps in the **CD40106** can be utilized as noise buffers. This solution ensures that each waveform can have an isolated noise blend without any interaction or interference between them.

#### **Solution Overview**

1. **Noise Buffering Using CD40106**:
   - The **CD40106** has **Schmitt trigger inverters** that can be used as buffers to create individual noise signals for each waveform.
   - Each of the remaining inverters in the **CD40106** will be used to buffer the noise output, allowing isolated distribution of the noise to the respective waveforms.

2. **Noise Routing and Blending**:
   - The **output of the noise amplifier (U5A)** will be the **common noise signal**.
   - This common noise signal will be routed to the **inputs of 5 separate inverters** in the **CD40106**.
   - Each inverter output will provide an isolated noise signal for blending with a specific waveform.

3. **Blending Noise with Each Waveform**:
   - The **outputs of the CD40106 inverters** will be used to blend noise with the waveforms (sawtooth, triangle, sine, pulse).
   - **Blend Control**: A **blend potentiometer (e.g., RV8)** will be used in series between each inverter output and the waveform to adjust the noise level individually for each waveform.
   - The noise from each inverter will then be connected to the respective waveform channel using a **mixing resistor (e.g., R21, R22, R23, R24)**.

4. **Summing Amplifier for Each Waveform**:
   - Each waveform (e.g., sawtooth, triangle, sine, pulse) will have a dedicated **op-amp summing stage** (using available op-amp sections in **TL072** or another op-amp).
   - This op-amp stage will sum the original waveform signal and the buffered noise signal, providing the final blended output for each waveform.

#### **Detailed Step-by-Step Implementation**

1. **Noise Source and Amplification**:
   - Keep the existing noise generator circuit intact, up to the **amplification and filtering stages** using **U5A**.
   - The **output of U5A** serves as the **common noise signal**.

2. **Buffering Noise with CD40106**:
   - **Connect the noise output** from **U5A** to the **inputs of 5 separate inverters** in the **CD40106**.
   - Each inverter will provide an isolated noise output for blending.

3. **Noise Blending for Each Waveform**:
   - **Inverter Outputs**: Use the outputs of the 5 inverters to feed the noise signal to each waveform:
     - **Sawtooth**: One inverter output goes to blend with the sawtooth waveform.
     - **Triangle**: One inverter output goes to blend with the triangle waveform.
     - **Sine**: One inverter output goes to blend with the sine waveform.
     - **Pulse**: One inverter output goes to blend with the pulse waveform.
   - **Blend Control**: Use a **potentiometer (e.g., RV8)** in series between each inverter output and the respective waveform blending resistor to adjust the noise level for each waveform individually.
   - **Mixing Resistors**: Connect each potentiometer wiper to a **mixing resistor (R21, R22, R23, R24)**, which will blend the noise with the respective waveform.

4. **Summing Amplifier for Blended Output**:
   - Use an op-amp stage (e.g., from **TL072**) to sum the **original waveform signal** and the **noise signal** from the corresponding inverter.
   - This op-amp will output the **final blended signal** for each waveform.

#### **Advantages of This Approach**

1. **Independent Noise Control**: Each waveform can have its own independent noise level, ensuring that the noise blend for one waveform does not affect the others.
2. **No Signal Interaction**: Since each waveform has a dedicated noise buffer, there is no cross-talk or interference between waveforms.
3. **Effective Use of CD40106**: Utilizing the remaining inverters in the **CD40106** helps to minimize the need for additional components and make efficient use of available resources.

#### **Considerations**

- **Noise Characteristics**: The **CD40106** inverters introduce a Schmitt trigger characteristic, which may slightly shape the noise signal. However, this should still be suitable for blending with analog signals in most synthesizer applications.
- **Decoupling**: Ensure proper decoupling of the power supply pins of the **CD40106** to maintain stability and reduce noise.

#### **Bill of Materials (BOM) Update**

| Part Description | Reference | Value | Suggested Part Number | Quantity |
|---|---|---|---|---|
| NPN Transistor | Q1 | BC547 | BC547 | 1 |
| Collector Resistor | R15 | 100kΩ | 1/4W, 1% Tolerance | 1 |
| Coupling Capacitor | C8 | 10μF | Electrolytic | 1 |
| Amplification Reference Resistor | R16 | 1MΩ | 1/4W, 1% Tolerance | 1 |
| Feedback Resistor (U5A) | R17 | 470kΩ | 1/4W, 1% Tolerance | 1 |
| Inverting Input Resistor (U5A) | R18 | 10kΩ | 1/4W, 1% Tolerance | 1 |
| High-Pass Filter Capacitor | C10 | 100nF | Ceramic | 1 |
| High-Pass Filter Potentiometer | RV7 | 50kΩ | Linear Taper | 1 |
| Low-Pass Filter Capacitor | C9 | 10nF | Ceramic | 1 |
| Low-Pass Filter Potentiometer | RV6 | 50kΩ | Linear Taper | 1 |
| Resistor for Low-Pass Wiper | R19 | 10kΩ | 1/4W, 1% Tolerance | 1 |
| Mixer Op-Amp | U5B, U6A, U6B | TL072 | TL072CN | 3 |
| Mixing Resistors | R20, R21, R22, R23, R24 | 100kΩ | 1/4W, 1% Tolerance | 5 |
| Blend Control Potentiometers | RV8 (x4) | 50kΩ | Linear Taper | 4 |
| Mixer Feedback Resistor | R25 (x4) | 100kΩ | 1/4W, 1% Tolerance | 4 |
| Decoupling Capacitors | C12, C13 | 100nF | Ceramic | 2 |
| Inverter Buffer (Noise Distribution) | CD40106 | - | CD40106 | 1 |

This updated BOM includes the components needed for implementing independent noise blending using the **CD40106** and additional op-amp stages for mixing. Let me know if you need more details or further assistance!

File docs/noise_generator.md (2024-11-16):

### **Noise Generator with Adjustable Noise Color and Blend Control for All Waveforms**

The **Noise Generator** is used to produce a random waveform that is useful in various synthesis applications, such as emulating natural sounds or adding randomness to modulation. This updated version includes features for **adjustable noise color or tone** and **blend control**, allowing you to shape the noise output and mix it with all generated waveforms (sawtooth, triangle, sine, pulse) in an adjustable manner.

#### **1. Key Components**

- **NPN Transistor (Q1 - BC547)** for generating noise
- **Op-Amp (U6A - TL072 or similar)** for amplification and filtering
- **Op-Amp (U6B - TL072)** for mixing noise with waveforms
- **Resistors, Capacitors, and Potentiometers** for biasing, filtering, color adjustment, and blending

#### **Step-by-Step Schematic Routing**

##### **1. Transistor Noise Source**

- **NPN Transistor (Q1)**:
  - Use an **NPN transistor** such as **BC547**.
  - Connect the **collector** of **Q1** to **+12V** through a **resistor R15 (100kΩ)**.
  - Connect the **emitter** of **Q1** to **ground**.
  - The **base** of **Q1** should be left **floating** (unconnected) to allow thermal noise to be generated by the transistor.
  - The noise is generated by the random movement of charge carriers in the transistor junction, creating a broad-spectrum signal.

##### **2. Amplification Stage (Op-Amp U6A)**

- **Coupling Capacitor (C10)**:
  - Use a **coupling capacitor (C10, 10μF)** to block any DC component from the noise signal.
  - Connect **C10** between the **collector** of **Q1** and the **non-inverting input (+)** of **op-amp U6A**.

- **Amplification Resistor Network**:
  - Use a **resistor (R16, 1MΩ)** between the **non-inverting input (+)** of **U6A** and **ground** to provide a reference for the noise signal.
  - Add a **feedback resistor (R17, 470kΩ)** between the **output (pin 1)** of **U6A** and the **inverting input (-) (pin 2)** to set the gain of the amplification stage.
  - Connect a **resistor (R18, 10kΩ)** between the **inverting input (-)** of **U6A** and **ground**.

##### **3. Adjustable Noise Color Filtering**

- **Low-Pass and High-Pass Filtering**:
  - To provide adjustable noise color, use a combination of **low-pass** and **high-pass filters** with potentiometers.
  - **Low-Pass Filter**:
    - Add a **capacitor (C11, 10nF)** and a **potentiometer (RV6, 50kΩ)** in series between the **output of U6A** and **ground**.
    - The wiper of **RV6** should be connected back to the **output** of **U6A** through a **resistor (R19, 10kΩ)**. This allows you to adjust the cutoff frequency of the low-pass filter, effectively controlling the high-frequency content of the noise.
  - **High-Pass Filter**:
    - Add a **capacitor (C14, 100nF)** in series with a **potentiometer (RV7, 50kΩ)** between the **output of U6A** and the **final noise output**.
    - The wiper of **RV7** acts as the output for the **high-pass filtered signal**, allowing control over the low-frequency content.

##### **4. Noise Blend Control for All Waveforms**

- **Mixing Noise with All Waveforms**:
  - To blend the noise with all generated waveforms (sawtooth, triangle, sine, pulse), use a **dual op-amp mixer** configuration.
  - **Mixer Op-Amp (U6B - TL072)**:
    - Use an **op-amp U6B** for mixing the noise signal with other waveforms.
  - **Mixing Resistors**:
    - Use **resistor R20 (100kΩ)** to connect the **noise output** to the **inverting input (-)** of **U6B**.
    - Use **resistors R21, R23, R24, and R25 (100kΩ each)** to connect the **sawtooth, triangle, sine, and pulse wave outputs** respectively to the **inverting input (-)** of **U6B**.
  - **Blend Control Potentiometer (RV8)**:
    - Add a **potentiometer (RV8, 50kΩ)** between the **noise signal** and **ground** to adjust the amount of noise mixed in.
    - The **wiper** of **RV8** should be connected to the **inverting input (-)** of **U6B** through **R20** to allow the adjustment from **no noise** to **a lot of noise**.
  - **Feedback Resistor**:
    - Connect a **resistor (R22, 100kΩ)** between the **output (pin 7)** of **U6B** and the **inverting input (-)** to set the gain for the mixer stage.

##### **5. Power Supply for Op-Amp (U6A & U6B)**

- **Power Supply**:
  - Ensure **pin 8** of **U6A and U6B** is connected to **+12V**, and **pin 4** is connected to **-12V**.

- **Decoupling Capacitors**:
  - Place **decoupling capacitors (C12, C13 - 100nF each)** between **+12V and ground** and **-12V and ground** to filter any power supply noise.

#### **Summary of Connections**

1. **Transistor Noise Source**:
   - **Collector of Q1** to **+12V** via **R15 (100kΩ)**.
   - **Emitter of Q1** to **ground**.
   - **Base of Q1** left **floating**.
2. **Coupling Capacitor**:
   - **C10 (10μF)** between the **collector of Q1** and the **non-inverting input (+)** of **U6A**.
3. **Amplification Resistor Network**:
   - **R16 (1MΩ)** between **non-inverting input (+)** of **U6A** and **ground**.
   - **R17 (470kΩ)** between the **output** and **inverting input (-)** of **U6A**.
   - **R18 (10kΩ)** between **inverting input (-)** of **U6A** and **ground**.
4. **Adjustable Noise Color Filtering**:
   - **Low-Pass Filter**: **C11 (10nF)** in series with **RV6 (50kΩ)** between the **output of U6A** and **ground**. **Wiper** of **RV6** to the **output** through **R19 (10kΩ)**.
   - **High-Pass Filter**: **C14 (100nF)** in series with **RV7 (50kΩ)** between the **output of U6A** and the **final noise output**.
5. **Noise Blend Control for All Waveforms**:
   - **Mixer Op-Amp U6B**: Connect **noise output** through **R20 (100kΩ)** and **wave outputs** (sawtooth, triangle, sine, pulse) through **R21, R23, R24, R25 (100kΩ each)** to the **inverting input (-)** of **U6B**.
   - **Blend Control Potentiometer (RV8)**: Connect **RV8 (50kΩ)** between the **noise signal** and **ground** to adjust noise amount.
   - **Feedback Resistor (R22, 100kΩ)** between **output (pin 7)** of **U6B** and **inverting input (-)**.
6. **Power Supply and Decoupling**:
   - **+12V** to **pin 8**, **-12V** to **pin 4**.
   - **C12 and C13 (100nF)** for decoupling between **power pins** and **ground**.

This configuration will provide a **white noise source** with adjustable color suitable for synthesizer applications, along with a blend control to mix the noise with all generated waveforms in an adjustable manner, from no noise to a lot of noise.

### **Bill of Materials (BOM)**

| Part Description | Reference | Value | Suggested Part Number | Quantity |
|---|---|---|---|---|
| NPN Transistor | Q1 | BC547 | BC547 | 1 |
| Collector Resistor | R15 | 100kΩ | 1/4W, 1% Tolerance | 1 |
| Coupling Capacitor | C10 | 10μF | Electrolytic | 1 |
| Amplification Reference Resistor | R16 | 1MΩ | 1/4W, 1% Tolerance | 1 |
| Feedback Resistor (U6A) | R17 | 470kΩ | 1/4W, 1% Tolerance | 1 |
| Inverting Input Resistor (U6A) | R18 | 10kΩ | 1/4W, 1% Tolerance | 1 |
| Low-Pass Filter Capacitor | C11 | 10nF | Ceramic | 1 |
| Low-Pass Filter Potentiometer | RV6 | 50kΩ | Linear Taper | 1 |
| High-Pass Filter Capacitor | C14 | 100nF | Ceramic | 1 |
| High-Pass Filter Potentiometer | RV7 | 50kΩ | Linear Taper | 1 |
| Resistor for Low-Pass Wiper | R19 | 10kΩ | 1/4W, 1% Tolerance | 1 |
| Mixer Op-Amp | U6B | TL072 | TL072CN | 1 |
| Mixing Resistors | R20, R21, R23, R24, R25 | 100kΩ | 1/4W, 1% Tolerance | 5 |
| Blend Control Potentiometer | RV8 | 50kΩ | Linear Taper | 1 |
| Mixer Feedback Resistor | R22 | 100kΩ | 1/4W, 1% Tolerance | 1 |
| Decoupling Capacitors | C12, C13  | 100nF | Ceramic | 2 |

This BOM lists the components needed for the noise generator with adjustable noise color and blend control, including the transistor, op-amp, resistors, capacitors, and potentiometers. Let me know if you need more details or further assistance!

=========================
MIXER SOLUTION
=========================
### **Utilizing CD40106 for Independent Noise Blending with Each Waveform**

To achieve independent noise blending with each waveform output (sawtooth, triangle, sine, pulse), the remaining 5 op-amps in the **CD40106** can be utilized as noise buffers. This solution ensures that each waveform can have an isolated noise blend without any interaction or interference between them.

#### **Solution Overview**

1. **Noise Buffering Using CD40106**:
   - The **CD40106** has **Schmitt trigger inverters** that can be used as buffers to create individual noise signals for each waveform.
   - Each of the remaining inverters in the **CD40106** will be used to buffer the noise output, allowing isolated distribution of the noise to the respective waveforms.

2. **Noise Routing and Blending**:
   - The **output of the noise amplifier (U5A)** will be the **common noise signal**.
   - This common noise signal will be routed to the **inputs of 5 separate inverters** in the **CD40106**.
   - Each inverter output will provide an isolated noise signal for blending with a specific waveform.

3. **Blending Noise with Each Waveform**:
   - The **outputs of the CD40106 inverters** will be used to blend noise with the waveforms (sawtooth, triangle, sine, pulse).
   - **Blend Control**: A **blend potentiometer (e.g., RV8)** will be used in series between each inverter output and the waveform to adjust the noise level individually for each waveform.
   - The noise from each inverter will then be connected to the respective waveform channel using a **mixing resistor (e.g., R21, R22, R23, R24)**.

4. **Summing Amplifier for Each Waveform**:
   - Each waveform (e.g., sawtooth, triangle, sine, pulse) will have a dedicated **op-amp summing stage** (using available op-amp sections in **TL072** or another op-amp).
   - This op-amp stage will sum the original waveform signal and the buffered noise signal, providing the final blended output for each waveform.

#### **Step-by-Step Updated Schematic Routing**

1. **Noise Source and Amplification**:
   - **Transistor Noise Source (Q1 - BC547)**: Connect the **collector** of **Q1** to **+12V** via **R15 (100kΩ)**. The **emitter** of **Q1** is connected to **ground**.
   - The **base** of **Q1** is left **floating** to generate thermal noise.
   - The noise signal is then coupled through **C8 (10μF)** to the **non-inverting input (+)** of **op-amp U5A (TL072)**.
   - **R16 (1MΩ)** sets a reference for the **non-inverting input (+)**, while **R17 (470kΩ)** and **R18 (10kΩ)** set the gain for the amplification stage.
   - The amplified noise signal is available at the **output of U5A (pin 1)**.

2. **Distribute Noise to CD40106 Inverters**:
   - **Amplified Noise Output**: Connect the output of **U5A** (pin 1) to the **inputs of 5 separate inverters** in the **CD40106** (e.g., pins 1, 3, 5, 9, and 11).
   - Each inverter will output a buffered version of the noise signal.

3. **Noise Blending for Each Waveform**:
   - **Inverter Outputs**: The **outputs of the inverters** (e.g., pins 2, 4, 6, 10, and 12) will each provide an isolated noise signal.
   - **Blend Control for Each Waveform**:
     - Connect the **output of each inverter** to a **blend potentiometer (RV8)**.
     - The **wiper** of each potentiometer should be connected to a **mixing resistor** (**R21, R22, R23, R24**).
     - The other side of each mixing resistor will connect to the respective waveform channel for blending.
   - **Waveform Channels**:
     - **Sawtooth Waveform**: Blend noise output through **R21 (100kΩ)**.
     - **Triangle Waveform**: Blend noise output through **R22 (100kΩ)**.
     - **Sine Waveform**: Blend noise output through **R23 (100kΩ)**.
     - **Pulse Waveform**: Blend noise output through **R24 (100kΩ)**.

4. **Summing Amplifier for Blended Output**:
   - **Summing Amplifier Setup**: Use an available op-amp section (e.g., **U6A, U6B** from **TL072**) to sum the **original waveform** and the **noise signal**.
   - **Waveform Input**: Connect the original waveform output (e.g., sawtooth, triangle, sine, pulse) to the **non-inverting input (+)** of the respective op-amp.
   - **Noise Input**: Connect the **noise signal** (after blending resistor) to the **inverting input (-)** of the op-amp through a **mixing resistor**.
   - **Feedback Resistor**: Use a **feedback resistor (R25 - 100kΩ)** between the **output** and the **inverting input (-)** of each op-amp to set the gain for the blended output.
   - The **output of each op-amp** will be the **final blended waveform**, which can be routed to the output jacks or further processing stages.

#### **Advantages of This Approach**

1. **Independent Noise Control**: Each waveform can have its own independent noise level, ensuring that the noise blend for one waveform does not affect the others.
2. **No Signal Interaction**: Since each waveform has a dedicated noise buffer, there is no cross-talk or interference between waveforms.
3. **Effective Use of CD40106**: Utilizing the remaining inverters in the **CD40106** helps to minimize the need for additional components and make efficient use of available resources.

#### **Considerations**

- **Noise Characteristics**: The **CD40106** inverters introduce a Schmitt trigger characteristic, which may slightly shape the noise signal. However, this should still be suitable for blending with analog signals in most synthesizer applications.
- **Decoupling**: Ensure proper decoupling of the power supply pins of the **CD40106** to maintain stability and reduce noise.

#### **Bill of Materials (BOM) Update**

| Part Description | Reference | Value | Suggested Part Number | Quantity |
|---|---|---|---|---|
| NPN Transistor | Q1 | BC547 | BC547 | 1 |
| Collector Resistor | R15 | 100kΩ | 1/4W, 1% Tolerance | 1 |
| Coupling Capacitor | C8 | 10μF | Electrolytic | 1 |
| Amplification Reference Resistor | R16 | 1MΩ | 1/4W, 1% Tolerance | 1 |
| Feedback Resistor (U5A) | R17 | 470kΩ | 1/4W, 1% Tolerance | 1 |
| Inverting Input Resistor (U5A) | R18 | 10kΩ | 1/4W, 1% Tolerance | 1 |
| High-Pass Filter Capacitor | C10 | 100nF | Ceramic | 1 |
| High-Pass Filter Potentiometer | RV7 | 50kΩ | Linear Taper | 1 |
| Low-Pass Filter Capacitor | C9 | 10nF | Ceramic | 1 |
| Low-Pass Filter Potentiometer | RV6 | 50kΩ | Linear Taper | 1 |
| Resistor for Low-Pass Wiper | R19 | 10kΩ | 1/4W, 1% Tolerance | 1 |
| Mixer Op-Amp | U5B, U6A, U6B | TL072 | TL072CN | 3 |
| Mixing Resistors | R20, R21, R22, R23, R24 | 100kΩ | 1/4W, 1% Tolerance | 5 |
| Blend Control Potentiometers | RV8 (x4) | 50kΩ | Linear Taper | 4 |
| Mixer Feedback Resistor | R25 (x4) | 100kΩ | 1/4W, 1% Tolerance | 4 |
| Decoupling Capacitors | C12, C13 | 100nF | Ceramic | 2 |
| Inverter Buffer (Noise Distribution) | CD40106 | - | CD40106 | 1 |

This updated BOM includes the components needed for implementing independent noise blending using the **CD40106** and additional op-amp stages for mixing. Let me know if you need more details or further assistance!

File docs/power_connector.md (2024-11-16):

### **Eurorack Power Connector Improvement**

#### **Schematic for Power Connector Improvement**
1. **Connector (J9)**:
   - 16-pin Eurorack power connector.
   - Pins are distributed as follows:
     - Pins 1, 2: **-12V**
     - Pins 3, 4, 5, 6, 7, 8: **GND**
     - Pins 9, 10: **+12V**
     - Pins 11, 12: **+5V**
     - Pins 13, 14: **CV IN (Optional)**
     - Pins 15, 16: **GATE (Optional)**

2. **Reverse Polarity Protection Diode**:
   - Use a **Schottky diode (D1)** such as **1N5819** in series with each voltage rail (+12V and -12V). This will protect against incorrect connection.
   - Connect the **anode** of the diode to the incoming power supply line and the **cathode** to the power rail input to the module.

3. **Filtering Capacitors**:
   - Add the following capacitors near the power pins of the connector:
     - **100nF ceramic capacitors (C1, C2)** between **+12V** and **GND**, and between **-12V** and **GND** for high-frequency filtering.
     - **47μF electrolytic capacitors (C3, C4)** between **+12V** and **GND**, and between **-12V** and **GND** for bulk decoupling to reduce power ripple.

4. **Pin Duplication**:
   - Multiple **GND pins** (pins 3 to 8) should be connected together to ensure proper grounding.
   - **+12V** and **-12V** pins (pins 1, 2, 9, 10) should also be duplicated for robust power distribution.
   - Ensure the **+5V**, **CV IN**, and **GATE** signals are clearly marked and routed for optional use.

#### **Bill of Materials (BOM)**

| Part Number | Description | Quantity |
|---|---|---|
| J9 | 16-Pin Eurorack Power Connector | 1 |
| D1, D2 | Schottky Diodes (1N5819 or equivalent) | 2 |
| C1, C2 | 100nF Ceramic Capacitors | 2 |
| C3, C4 | 47μF Electrolytic Capacitors | 2 |
| Wires | For Pin Connections | As needed|

#### **Detailed Guide of Pin Routing**
1. **Pins 1, 2 - -12V**:
   - Route both pins to the **-12V** power rail.
   - Connect a **Schottky diode (D1)** in series with the power line.
   - After the diode, add **C1 (100nF ceramic)** and **C3 (47μF electrolytic)** capacitors between **-12V** and **GND**.

2. **Pins 3, 4, 5, 6, 7, 8 - GND**:
   - Connect all GND pins together for a solid ground plane.
   - Ensure that **C1, C2, C3, C4** are all connected to this common GND plane.

3. **Pins 9, 10 - +12V**:
   - Route both pins to the **+12V** power rail.
   - Connect a **Schottky diode (D2)** in series with the power line.
   - After the diode, add **C2 (100nF ceramic)** and **C4 (47μF electrolytic)** capacitors between **+12V** and **GND**.

4. **Pins 11, 12 - +5V**:
   - Ensure proper decoupling with a **100nF capacitor** close to the +5V line.

5. **Pins 13, 14 - CV IN (Optional)**:
   - Route these pins to a **CV input** if applicable in your circuit.

6. **Pins 15, 16 - GATE (Optional)**:
   - Route these pins to the **Gate input** for any triggering function needed.

#### **Summary**
- Use **Schottky diodes** for reverse polarity protection on the power rails.
- Add **100nF ceramic** and **47μF electrolytic** capacitors for proper power filtering.
- Duplicate **GND**, **+12V**, and **-12V** pins for robustness and to reduce potential issues due to poor connections.
- Ensure proper routing for optional signals like **+5V, CV IN, and GATE** to provide flexibility for future modifications.

These improvements will help make your Eurorack module more reliable, with reduced power noise and greater resilience to accidental misconnection.

### **Eurorack Power Connector Improvement with Single LED Indicator**

#### **Schematic for Power Connector Improvement**
1. **Connector (J9)**:
   - 16-pin Eurorack power connector.
   - Pins are distributed as follows:
     - Pins 1, 2: **-12V**
     - Pins 3, 4, 5, 6, 7, 8: **GND**
     - Pins 9, 10: **+12V**
     - Pins 11, 12: **+5V**
     - Pins 13, 14: **CV IN (Optional)**
     - Pins 15, 16: **GATE (Optional)**

2. **Reverse Polarity Protection Diode**:
   - Use a **Schottky diode (D1)** such as **1N5819** in series with each voltage rail (+12V and -12V). This will protect against incorrect connection.
   - Connect the **anode** of the diode to the incoming power supply line and the **cathode** to the power rail input to the module.

3. **Filtering Capacitors**:
   - Add the following capacitors near the power pins of the connector:
     - **100nF ceramic capacitors (C1, C2)** between **+12V** and **GND**, and between **-12V** and **GND** for high-frequency filtering.
     - **47μF electrolytic capacitors (C3, C4)** between **+12V** and **GND**, and between **-12V** and **GND** for bulk decoupling to reduce power ripple.

4. **Pin Duplication**:
   - Multiple **GND pins** (pins 3 to 8) should be connected together to ensure proper grounding.
   - **+12V** and **-12V** pins (pins 1, 2, 9, 10) should also be duplicated for robust power distribution.
   - Ensure the **+5V**, **CV IN**, and **GATE** signals are clearly marked and routed for optional use.

5. **Power LED Indicator**:
   - Add a single **LED (LED1)** with a series resistor for power indication.
   - Connect **LED1** in series with a **1kΩ resistor (R1)** between the **+5V** power rail and GND to indicate power status.

#### **Bill of Materials (BOM)**

| Part Number | Description | Quantity |
|---|---|---|
| J9 | 16-Pin Eurorack Power Connector | 1 |
| D1, D2 | Schottky Diodes (1N5819 or equivalent) | 2 |
| C1, C2 | 100nF Ceramic Capacitors | 2 |
| C3, C4 | 47μF Electrolytic Capacitors | 2 |
| LED1 | Power Indicator LED (+5V) | 1 |
| R1 | 1kΩ Resistor for LED current limiting | 1 |
| Wires | For Pin Connections | As needed|

#### **Detailed Guide of Pin Routing**
1. **Pins 1, 2 - -12V**:
   - Route both pins to the **-12V** power rail.
   - Connect a **Schottky diode (D1)** in series with the power line.
   - After the diode, add **C1 (100nF ceramic)** and **C3 (47μF electrolytic)** capacitors between **-12V** and **GND**.

2. **Pins 3, 4, 5, 6, 7, 8 - GND**:
   - Connect all GND pins together for a solid ground plane.
   - Ensure that **C1, C2, C3, C4** are all connected to this common GND plane.

3. **Pins 9, 10 - +12V**:
   - Route both pins to the **+12V** power rail.
   - Connect a **Schottky diode (D2)** in series with the power line.
   - After the diode, add **C2 (100nF ceramic)** and **C4 (47μF electrolytic)** capacitors between **+12V** and **GND**.

4. **Pins 11, 12 - +5V**:
   - Ensure proper decoupling with a **100nF capacitor** close to the +5V line.

5. **Pins 13, 14 - CV IN (Optional)**:
   - Route these pins to a **CV input** if applicable in your circuit.

6. **Pins 15, 16 - GATE (Optional)**:
   - Route these pins to the **Gate input** for any triggering function needed.

7. **Power LED Indicator**:
   - **+5V Indicator**: Connect **LED1** in series with **R1 (1kΩ resistor)** between **+5V** and **GND**.

#### **Summary**
- Use **Schottky diodes** for reverse polarity protection on the power rails.
- Add **100nF ceramic** and **47μF electrolytic** capacitors for proper power filtering.
- Duplicate **GND**, **+12V**, and **-12V** pins for robustness and to reduce potential issues due to poor connections.
- Ensure proper routing for optional signals like **+5V, CV IN, and GATE** to provide flexibility for future modifications.

These improvements will help make your Eurorack module more reliable, with reduced power noise and greater resilience to accidental misconnection.

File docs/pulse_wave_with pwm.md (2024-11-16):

### **Pulse Wave with PWM Control: Step-by-Step Schematic Routing**

The **Pulse Wave Generator with PWM (Pulse Width Modulation) Control** allows the width of the pulse wave to be adjusted in real time, giving a rich variety of timbral changes. Here is a detailed step-by-step guide to create a pulse wave generator with PWM control:

#### **1. Key Components**
- **Op-Amp (U5A - TL072 or similar)**
- **Comparator** for PWM control
- **Triangle Wave Input** for creating the pulse wave
- **PWM Input Signal** (for modulating the pulse width)
- **Potentiometer (RV5)** for manual PWM adjustment
- **Resistors and capacitors** for feedback and signal control

#### **Step-by-Step Schematic Routing**

##### **1. Triangle Wave Input to Comparator**
- **Input Signal**:
  - Use a **triangle waveform** from the previous oscillator stage.
  - Connect the **triangle wave input** to the **inverting input (-)** of the **comparator op-amp (U5A)** through a **resistor R11 (10kΩ)**. This signal acts as the reference for comparison and sets the waveform’s symmetry.

##### **2. Pulse Width Control via Potentiometer (RV5)**
- **PWM Control Potentiometer**:
  - Add a **potentiometer (RV5, 10kΩ - 50kΩ)** to adjust the **pulse width manually**.
  - **One terminal** of **RV5** should be connected to a **reference voltage**, typically derived from a stable supply like **+5V**.
  - The **other terminal** of **RV5** should be connected to **ground**.
  - The **wiper** of **RV5** should be connected to the **non-inverting input (+)** of the comparator op-amp (U5A).
  - This configuration allows you to manually control the threshold level, thus adjusting the pulse width.

##### **3. Adding PWM Modulation**
- **Modulation Input (PWM)**:
  - You can add an external modulation signal to change the **pulse width** automatically.
  - Connect the **PWM modulation input** to the **non-inverting input (+)** of **U5A** through a **resistor R12 (10kΩ)**.
  - This modulation signal could come from an LFO (Low-Frequency Oscillator), an envelope generator, or any other modulation source. This will provide dynamic control over the pulse width.

##### **4. Comparator Output for Pulse Wave**
- **Comparator Output**:
  - The **output of U5A (pin 1)** will produce the **pulse wave**.
  - The comparator will compare the triangle wave to the PWM control voltage, outputting a **high** or **low** signal depending on whether the triangle input is above or below the threshold set by the PWM control. This produces the **pulse wave**.
  - **Output Resistor (R13, 1kΩ)**: Add **R13** at the output of **U5A** to limit the current.

##### **5. Feedback and Stability**
- **Hysteresis Resistor for Stability**:
  - To add **hysteresis** (which prevents the comparator from rapidly switching due to noise), connect a **resistor (R14, 1MΩ)** between the **output (pin 1)** of **U5A** and the **non-inverting input (+)**.
  - This feedback introduces a small amount of positive feedback, making the output more stable and reducing unwanted oscillation around the switching point.

##### **6. Power Supply for Op-Amp (U5A)**
- **Power Supply**:
  - Ensure **pin 8** of **U5A** is connected to **+12V**, and **pin 4** is connected to **-12V**.
- **Decoupling Capacitors**:
  - Place **decoupling capacitors (C8, C9 - 100nF each)** between **+12V and ground** and **-12V and ground** to filter any supply noise.

#### **Summary of Connections**
1. **Triangle Wave Input**:
   - Connect to the **inverting input (-)** of the comparator through **R11 (10kΩ)**.
2. **Manual PWM Control (RV5)**:
   - Connect **RV5** between **+5V** and **ground**.
   - The **wiper** goes to the **non-inverting input (+)** of **U5A**.
3. **Modulation Input**:
   - Connect the **PWM modulation signal** to the **non-inverting input (+)** through **R12 (10kΩ)**.
4. **Comparator Output**:
   - **U5A output (pin 1)** generates the **pulse wave**.
   - Add **R13 (1kΩ)** to limit output current.
5. **Hysteresis Feedback**:
   - Connect **R14 (1MΩ)** between the **output** and the **non-inverting input (+)** of **U5A**.
6. **Power Supply and Decoupling**:
   - **+12V** to **pin 8**, **-12V** to **pin 4**.
   - **C8 and C9 (100nF)** for decoupling between **power pins** and **ground**.

This configuration will give you a **pulse wave output** with adjustable **PWM** through both manual control and external modulation, making it versatile for different synthesis applications.

### **Bill of Materials (BOM)**

| Part Description | Reference | Value | Suggested Part Number | Quantity |
|---|---|---|---|---|
| Potentiometer (Manual PWM Control) | RV5 | 10kΩ - 50kΩ  | Linear Taper | 1 |
| Op-Amp | U5A | TL072 | TL072CN | 1 |
| Input Resistor (Triangle Wave) | R11 | 10kΩ | 1/4W, 1% Tolerance | 1 |
| Input Resistor (PWM Modulation) | R12 | 10kΩ | 1/4W, 1% Tolerance | 1 |
| Output Resistor | R13 | 1kΩ | 1/4W, 1% Tolerance | 1 |
| Hysteresis Resistor | R14 | 1MΩ | 1/4W, 1% Tolerance | 1 |
| Decoupling Capacitors | C8, C9 | 100nF | Ceramic | 2 |

This BOM lists the components needed for the pulse wave generation with PWM control, including resistors, capacitors, potentiometers, and an op-amp. Feel free to ask if you need more details or further assistance with the design!

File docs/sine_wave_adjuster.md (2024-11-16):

### **Sine Wave Shaper: Complete Schematic Guide with Amplitude Control and Triangle Corner Shaping**

This guide explains how to design the **Sine Wave Shaper** with **amplitude control** and **triangle corner shaping** for better sine conversion, including a complete schematic routing, a Bill of Materials, and an operational overview.

#### **Step-by-Step Schematic Routing**

##### **1. Triangle Wave Input to Sine Shaper**
- **Input Signal**:
  - Connect the **triangle wave output** from the previous stage (triangle wave shaper) to the **inverting input (-)** of the op-amp **U3 (TL072)** through **resistor R9 (10kΩ)**. This resistor helps control the input signal.

##### **2. Diode Shaping Network for Sine Wave Conversion**
- **Diodes (D1, D2)**:
  - Use two **1N4148 diodes (D1 and D2)** to clip the triangle waveform, converting it to a sine wave.
  - Connect **D1** and **D2** in opposite directions, with their cathodes and anodes meeting at the **inverting input (-)** of **U3**. Connect the **other junction** (the free ends) of **D1 and D2** to **ground**. This forms a symmetric clipping point around ground, shaping the input triangle wave into a sine wave.
- **Triangle Corner Shaping Potentiometer (RV4)**:
  - Replace the fixed resistors in the shaping network with a **potentiometer (RV4, 10kΩ)** to control the clipping level.
  - Connect **one outer terminal** of **RV4** in series with **D1** and **D2**.
  - Connect the **middle wiper** of **RV4** to the **junction point** between **D1, D2**, and the **inverting input (-)** of **U3**. Adjusting **RV4** will allow you to fine-tune how much of the triangle wave is clipped, resulting in different sine wave characteristics.

##### **3. Feedback Network for Gain Control**
- **Feedback Resistor (R10)**:
  - Connect a **resistor (R10, 10kΩ)** between the **output of U3 (pin 1)** and the **inverting input (-) (pin 2)**. This resistor defines the gain and ensures proper feedback for sine shaping.
- **Optional Capacitor for Smoothing (C4)**:
  - You can add a **small capacitor (10pF to 33pF)** in parallel with **R10** to reduce high-frequency oscillations and smooth out the sine wave.

##### **4. Amplitude Control Potentiometer (RV3)**
- **Output of the Op-Amp**:
  - Connect the **output of the sine wave shaping op-amp** (U3) to one of the **outer terminals** of the potentiometer **(RV3, 10kΩ - 50kΩ)**.
- **Ground Connection**:
  - Connect the **other outer terminal** of **RV3** to **ground**.
- **Middle Wiper as Adjustable Output**:
  - The **middle wiper** will act as the **adjustable amplitude output**. This allows you to adjust the amplitude of the sine wave output to match other waveform levels or provide a desired output range.

##### **5. Power Supply for Op-Amp (U3)**
- **Op-Amp Power Supply**:
  - Connect **pin 8** of **U3** to the **+12V supply**.
  - Connect **pin 4** of **U3** to the **-12V supply**.
- **Decoupling Capacitors (C2, C3)**:
  - Place **100nF capacitors** between the **+12V and ground** and **-12V and ground** to stabilize the power supply and reduce noise.

### **Bill of Materials (BOM)**

| Part Description | Reference | Value | Suggested Part Number | Quantity |
|---|---|---|---|---|
| Potentiometer (Amplitude Control) | RV3 | 10kΩ - 50kΩ  | Linear Taper | 1 |
| Potentiometer (Corner Shaping) | RV4 | 10kΩ | Linear Taper | 1 |
| Diodes for Sine Shaping | D1, D2 | 1N4148 | 1N4148 | 2 |
| Op-Amp | U3 | TL072 | TL072CN | 1 |
| Feedback Resistor | R10 | 10kΩ | 1/4W, 1% Tolerance | 1 |
| Input Resistor | R9 | 10kΩ | 1/4W, 1% Tolerance | 1 |
| Resistors (Optional for Limiting) | R7, R8 | 1kΩ | 1/4W, 1% Tolerance | 2 |
| Capacitors (Decoupling) | C2, C3 | 100nF | Ceramic | 2 |
| Capacitor for Smoothing (Optional) | C4 | 10pF - 33pF | Ceramic | 1 |

### **Operational Overview**

- **Amplitude Control**: By adjusting **RV3**, you control the final **output level** of the sine wave. This helps match its amplitude to the other waveforms or provides a customizable output level.
- **Shaping Adjustment**: **RV4** allows you to control how much the **triangle corners are rounded** by adjusting the diode clipping point. This gives you a way to tune how close the waveform resembles an ideal sine wave—adjusting between more of a triangle or a smoothly rounded sine shape.

### **Summary of Changes**

- Add a **potentiometer (RV3)** at the output to control the **amplitude** of the sine wave.
- Replace the fixed resistors in the **diode shaping network** with a **potentiometer (RV4)** to adjust the curvature and **symmetry** of the sine wave.
- Add a **feedback resistor (R10)** to define gain, with an optional capacitor (C4) to smooth the sine wave output.

These changes provide more flexibility and control over both the **waveform's shape** and its **amplitude**, making the sine wave more versatile for use in different applications. Let me know if you need any more information or guidance on implementing these changes!

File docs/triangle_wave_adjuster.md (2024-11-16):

### **Modification for Adjustable Triangle Wave Symmetry**

To add **adjustable symmetry control** for the triangle wave in your VCO design, you can modify the circuit to include a **potentiometer** that allows you to tweak the balance of the **resistor divider**. Here’s how to implement it:

#### **Step-by-Step Modification for Adjustable Triangle Wave Symmetry**

1. **Replace Resistor Divider with Potentiometer**:
   - Instead of using fixed resistors **R4** and **R5** for the voltage divider, replace them with a **single potentiometer (VR1)**.
   - Use a **10kΩ potentiometer (VR1)**, which will allow you to vary the resistance on either side of the divider and thus control the symmetry of the triangle wave.

2. **Wiring the Potentiometer**:
   - Connect the **middle wiper** of the potentiometer (VR1) to the **inverting input (-)** of **U2**.
   - Connect one of the **outer terminals** of VR1 to the **sawtooth input** (coming from the output of **U1A** through **R4**).
   - Connect the other **outer terminal** of VR1 to **ground**.

3. **Adjusting Symmetry**:
   - By adjusting the position of the **wiper** of the potentiometer, you can change the ratio between the resistance to the sawtooth input and the resistance to ground.
   - This adjustment changes how the op-amp processes the sawtooth input, allowing you to control the **linearity** of the triangle waveform.
   - When the wiper is in the center, the resistances are equal, resulting in a symmetric triangle wave. Moving the wiper in either direction will adjust the up-slope and down-slope, thus changing the symmetry.

4. **Adding Fixed Resistor for Range Control** (Optional):
   - You could add **fixed resistors (e.g., 1kΩ)** in series with each side of the potentiometer to limit the range of adjustment, preventing the wave from becoming too distorted.

#### **Revised Schematic Routing**

- **Sawtooth Wave Input**:
  - Connect the **sawtooth waveform** from the output of **U1A** to one of the **outer terminals** of the potentiometer **(VR1)**.
  - The other **outer terminal** of **VR1** should be connected to **ground**.
- **Inverting Input of U2**:
  - Connect the **middle wiper** of the potentiometer **(VR1)** to the **inverting input (-)** of the op-amp **U2**.
  - The **feedback resistor (R6)** should remain between the **output of U2** and the **inverting input (-)**.

#### **Operational Notes**

- **Adjusting the potentiometer** allows you to change the symmetry of the triangle wave.
- This provides flexibility to achieve different harmonic content in the waveform, which can be useful in sound design.

#### **Summary**

- Replacing the fixed resistor divider (R4, R5) with a **10kΩ potentiometer** allows you to **manually adjust the symmetry** of the triangle wave.
- This modification provides more control over the waveform shape, making your VCO more versatile for different sonic characteristics.

Using this approach will enhance the versatility of your **Triangle Wave Shaper** by allowing for real-time control over the waveform symmetry, adding expressiveness to your synthesizer.

#### **Bill of Materials (BOM)**

| Part Description | Reference | Value | Suggested Part Number | Quantity |
|---|---|---|---|---|
| Op-Amp | U2 | TL072 | TL072CN | 1 |
| Potentiometer (Symmetry Control)  | VR1 | 10kΩ | Linear Taper | 1 |
| Fixed Resistors (Optional) | R4, R5 | 1kΩ | 1/4W, 1% Tolerance | 2 |
| Feedback Resistor | R6 | 10kΩ | 1/4W, 1% Tolerance | 1 |

### **Detailed Step-by-Step Connection Routing for Triangle Wave Shaper**

This step-by-step guide explains how to modify the **Triangle Wave Shaper** by adding a potentiometer to adjust the symmetry of the triangle waveform.

#### **Step-by-Step Routing**:

1. **Connecting the Sawtooth Wave Input**:
   - **Sawtooth Output from Integrator (U1A)**:
     - Locate the **output pin of U1A** (the previous integrator op-amp stage) where the **sawtooth waveform** is generated.
     - Connect this sawtooth output to **one of the outer terminals** of the **potentiometer (VR1, 10kΩ)**. This terminal will provide the varying input voltage to help shape the triangle wave.

2. **Grounding the Potentiometer**:
   - **Ground Connection for VR1**:
     - Connect the **other outer terminal** of **VR1** to **ground**. This sets a reference point for adjusting the symmetry, which will allow for changes in the linearity of the triangle waveform.

3. **Connecting the Potentiometer Wiper**:
   - **Middle Wiper of Potentiometer (VR1)**:
     - Connect the **middle wiper** of the potentiometer to the **inverting input (-)** of **op-amp U2**. This input will receive a variable voltage depending on the wiper's position, which influences how U2 shapes the input waveform.
     - The wiper acts as a variable resistor, altering the relative resistance between the sawtooth signal and ground.

4. **Adding Feedback Resistor to U2**:
   - **Feedback Resistor (R6)**:
     - Place a **10kΩ feedback resistor (R6)** between the **output of U2** and the **inverting input (-)**.
     - This feedback resistor helps determine the gain of the op-amp, ensuring that the output triangle waveform is correctly shaped based on the input and feedback configuration.

5. **Connecting Power to the Op-Amp (U2)**:
   - Ensure that the **op-amp U2 (TL072)** is powered correctly:
     - Connect **pin 8** of **U2** to the **+12V supply**.
     - Connect **pin 4** of **U2** to the **-12V supply**.
   - This provides the necessary bipolar power for the op-amp to handle the full range of the input signal.

6. **Output Triangle Wave**:
   - The **output of U2** will generate the **triangle waveform**.
   - You can take this output to the next stage, such as a **sine wave shaper**, or use it as a standalone output for further synthesis.

7. **Optional Fixed Resistors for Range Control**:
   - If you wish to **limit the range** of symmetry adjustment:
     - Place **1kΩ fixed resistors** in series with **each of the outer terminals** of the potentiometer.
     - These resistors will prevent the potentiometer from adjusting the symmetry too far, which could lead to distortion or unwanted wave characteristics.

#### **Summary of Connections**:

- **Sawtooth Input to VR1**: Connect the sawtooth waveform output from **U1A** to **one outer terminal** of the potentiometer (VR1).
- **Ground VR1**: Connect the **other outer terminal** of **VR1** to **ground**.
- **Potentiometer Wiper to U2**: Connect the **middle wiper** of the potentiometer to the **inverting input (-)** of the **op-amp U2**.
- **Feedback Resistor**: Connect a **10kΩ resistor (R6)** between the **output of U2** and the **inverting input (-)**.
- **Power U2**: Connect **+12V** to pin **8** and **-12V** to pin **4** of **U2**.

This routing guide ensures that the triangle wave can be adjusted for symmetry, giving you more flexibility in shaping the waveform and producing richer harmonic content. Let me know if you need further details or additional modifications!

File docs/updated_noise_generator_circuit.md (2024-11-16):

### **Updated Complete Schematic for Noise Circuit with Voltage-Controlled Blending and Mixer Using CD40106**

This updated schematic integrates the noise circuit with the voltage-controlled blending functionality, utilizing **2N5457 JFETs** as voltage-controlled amplifiers (VCAs). Additionally, the remaining inverters in the **CD40106** are used to create independent buffered noise outputs for each waveform. Each waveform (sawtooth, triangle, sine, pulse) controls the noise level individually, creating dynamic, modulated noise effects for each output.

#### **Key Sections of the Schematic**

1. **Noise Generation and Amplification**:
   - **Noise Source**: The noise is generated using **BC547 (Q1)**, with the **collector** connected to **+12V** via **R15 (100kΩ)**, and the **emitter** connected to **ground**. The **base** is left floating to produce thermal noise.
   - **Amplification Stage**: The noise signal is then coupled through **C8 (10μF)** to the **non-inverting input (+)** of **op-amp U5A (TL072)** for amplification.
     - **R16 (1MΩ)** sets a reference for the **non-inverting input (+)**.
     - **R17 (470kΩ)** and **R18 (10kΩ)** set the gain for the op-amp.
   - The amplified noise output is available at **pin 1** of **U5A**.

2. **Noise Buffering Using CD40106**:
   - The **amplified noise output** from **U5A** is routed to the **inputs of 5 separate inverters** in the **CD40106** (e.g., pins 1, 3, 5, 9, and 11).
   - Each inverter provides a buffered version of the noise signal, ensuring isolated noise distribution for blending with each waveform.

3. **Envelope Follower for Waveform Control Signal**:
   - Each waveform output (sawtooth, triangle, sine, pulse) is connected to an **envelope follower** circuit consisting of a **diode (1N4148)** and **capacitor (10μF)**.
   - The **diode (D1, D2, D3, D4)** and **capacitor (C14, C15, C16, C17)** create a control voltage proportional to the waveform's amplitude, which is then used to control the noise level.

4. **JFET-Based Voltage-Controlled Amplifier (VCA)**:
   - **JFETs (2N5457)** are used as VCAs to control the amplitude of the noise signal for each waveform.
   - The **drain** of each JFET (Q2, Q3, Q4, Q5) is connected to the respective **buffered noise output** from the **CD40106**.
   - The **gate** of each JFET receives the control voltage from the corresponding envelope follower (D1, C14, etc.).
   - The **source** of each JFET is connected to the respective waveform blending stage.

5. **Summing Mixer for Blended Output**:
   - After passing through the JFET VCA, the noise signal is summed with the respective waveform using an **op-amp summing mixer** (U7A, U7B - TL072).
   - Each waveform output is connected to the **non-inverting input (+)** of the op-amp.
   - The noise signal (after blending) is connected to the **inverting input (-)** of the op-amp through a **mixing resistor (R21, R22, R23, R24 - 100kΩ)**.
   - **Feedback resistors (R25, R26, R27, R28 - 100kΩ)** are used to set the gain for each summing stage, ensuring the correct blend of noise and waveform.

6. **Power Supply and Decoupling**:
   - Ensure **+12V** and **-12V** are properly connected to the power pins of all op-amps (pins **8** and **4** respectively for TL072).
   - Use **decoupling capacitors (C12, C13 - 100nF)** between **+12V** and **ground**, and **-12V** and **ground** to filter any power supply noise.

#### **Summary of Connections**

1. **Noise Source and Amplification**:
   - **BC547 (Q1)**: Collector to **+12V** via **R15 (100kΩ)**, emitter to **ground**.
   - **Amplified Noise**: Coupled through **C8 (10μF)** to **U5A** (TL072) for amplification.
2. **Noise Buffering Using CD40106**:
   - **Amplified Noise Output**: Connect the amplified noise output from **U5A** to the **inputs of 5 inverters** in **CD40106** (pins 1, 3, 5, 9, and 11).
   - **Buffered Noise Outputs**: Available at pins **2, 4, 6, 10, and 12** of the **CD40106**.
3. **Envelope Followers**:
   - **Waveform Outputs**: Connect each waveform output to an envelope follower (diode and capacitor) to generate a control voltage.
4. **JFET VCAs**:
   - **2N5457 (Q2, Q3, Q4, Q5)**: Drain connected to buffered noise from **CD40106**, gate receives control voltage from envelope follower, source to blending stage.
5. **Summing Mixer**:
   - **Op-Amps (U7A, U7B - TL072)**: Used to mix the original waveform and the noise signal for each waveform.
6. **Power Supply**:
   - **Decoupling Capacitors**: Place **C12, C13 (100nF)** close to the power pins of all op-amps.

#### **Bill of Materials (BOM) Update**

| Part Description | Reference | Value | Suggested Part Number | Quantity |
|---|---|---|---|---|
| NPN Transistor | Q1 | BC547 | BC547 | 1 |
| Collector Resistor | R15 | 100kΩ | 1/4W, 1% Tolerance | 1 |
| Coupling Capacitor | C8 | 10μF | Electrolytic | 1 |
| Amplification Reference Resistor | R16 | 1MΩ | 1/4W, 1% Tolerance | 1 |
| Feedback Resistor (U5A) | R17 | 470kΩ | 1/4W, 1% Tolerance | 1 |
| Inverting Input Resistor (U5A) | R18 | 10kΩ | 1/4W, 1% Tolerance | 1 |
| High-Pass Filter Capacitor | C10 | 100nF | Ceramic | 1 |
| High-Pass Filter Potentiometer | RV7 | 50kΩ | Linear Taper | 1 |
| Low-Pass Filter Capacitor | C9 | 10nF | Ceramic | 1 |
| Low-Pass Filter Potentiometer | RV6 | 50kΩ | Linear Taper | 1 |
| Resistor for Low-Pass Wiper | R19 | 10kΩ | 1/4W, 1% Tolerance | 1 |
| Mixer Op-Amp | U5B, U7A, U7B | TL072 | TL072CN | 3 |
| Mixing Resistors | R20, R21, R22, R23, R24 | 100kΩ | 1/4W, 1% Tolerance | 5 |
| Blend Control Potentiometers | RV8 (x4) | 50kΩ | Linear Taper | 4 |
| Mixer Feedback Resistor | R25, R26, R27, R28 | 100kΩ | 1/4W, 1% Tolerance | 4 |
| Decoupling Capacitors | C12, C13 | 100nF | Ceramic | 2 |
| Inverter Buffer (Noise Distribution) | CD40106 | - | CD40106 | 1 |
| JFET | Q2, Q3, Q4, Q5  | 2N5457 | 2N5457 | 4 |
| Diode for Envelope Follower | D1, D2, D3, D4  | 1N4148 | 1N4148 | 4 |
| Capacitor for Envelope Follower | C14, C15, C16, C17 | 10μF | Electrolytic | 4 |
| Resistors for VCA | R26, R27, R28, R29 | 100kΩ | 1/4W, 1% Tolerance | 4 |

#### **Step-by-Step Routing Guide**

1. **Noise Source and Amplification**:
   - Connect the **collector** of **Q1 (BC547)** to **+12V** via **R15 (100kΩ)**. Connect the **emitter** of **Q1** to **ground**. Leave the **base** of **Q1** floating to generate thermal noise.
   - Couple the noise through **C8 (10μF)** to the **non-inverting input (+)** of **U5A (TL072)**. Connect **R16 (1MΩ)** between the **non-inverting input (+)** and **ground**.
   - Set the gain of **U5A** using **R17 (470kΩ)** and **R18 (10kΩ)**. The amplified noise output is available at **pin 1** of **U5A**.

2. **Noise Buffering with CD40106**:
   - Connect the amplified noise output from **U5A** to the **inputs of 5 inverters** in **CD40106** (pins 1, 3, 5, 9, and 11).
   - The **buffered noise outputs** are available at **pins 2, 4, 6, 10, and 12**.

3. **Envelope Followers**:
   - Connect each waveform output (sawtooth, triangle, sine, pulse) to an **envelope follower** circuit (diode and capacitor).
   - Connect **diodes (D1, D2, D3, D4)** in series with **capacitors (C14, C15, C16, C17 - 10μF)** to generate control voltages proportional to waveform amplitudes.

4. **JFET VCAs**:
   - Connect the **drain** of each **JFET (2N5457 - Q2, Q3, Q4, Q5)** to the respective **buffered noise output** from **CD40106**.
   - Connect the **gate** of each JFET to the control voltage from the corresponding envelope follower.
   - Connect the **source** of each JFET to the respective waveform blending stage.

5. **Summing Mixer**:
   - Use **op-amps (U7A, U7B - TL072)** to mix the original waveform and noise for each waveform.
   - Connect the original waveform to the **non-inverting input (+)** and the noise signal (via blending resistor) to the **inverting input (-)** of the op-amp.
   - Use **feedback resistors (R25, R26, R27, R28 - 100kΩ)** to set the appropriate gain for each summing stage.

6. **Power Supply and Decoupling**:
   - Connect **+12V** and **-12V** to the power pins (**8** and **4** respectively) of each op-amp.
   - Place **decoupling capacitors (C12, C13 - 100nF)** between **+12V** and **ground**, and **-12V** and **ground** to filter power supply noise.

This configuration allows each waveform output to dynamically control the noise level using a JFET-based VCA, with the **CD40106** providing buffered noise signals for each path, resulting in a unique blended output for each waveform that varies according to its amplitude. Let me know if you need more details on any part of this updated schematic or further assistance!

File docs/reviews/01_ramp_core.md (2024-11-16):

### **Review of Sawtooth Core Oscillator Schematic (Ramp Core with CA3086/3046)**

This document provides a detailed review of the **Sawtooth Core Oscillator** schematic using the **CA3086/3046** transistor array for a VCO design. The analysis covers the key components, connections, and suggestions for improving the design.

#### **Key Observations**

1. **Op-Amp Integrator (U1A - TL072)**:
   - The **inverting input (-)** is correctly connected to **resistor R1 (100kΩ)**, which determines the charging rate.
   - **Capacitor C1 (22nF)** is properly connected between the **output of U1A** and the **inverting input** to perform the integration.
   - The **non-inverting input (+)** is connected to **ground**, which is also correct.

2. **Transistor Array (U3A - CA3086/3046)**:
   - **Q1 and Q2** from **CA3086/3046** are configured correctly for the exponential converter.
   - **CV IN** is connected to the **bases of Q1 and Q2**, which is correct.
   - **Collectors of Q1 and Q2** are connected as follows:
     - **Q1 Collector**: Connected to **R1** (which leads to the op-amp input) — this is correct for setting up the current source for integration.
     - **Q2 Collector**: Connected to **+12V**, which provides the supply voltage for the current mirror configuration. This connection is also correct.
   - The **emitters of Q1 and Q2** are tied together and connected to **ground via R3 (1kΩ)**. This provides a common reference point and helps maintain temperature stability — this is a correct approach for maintaining good thermal tracking.

3. **Reset Mechanism (Q2 and CD40106)**:
   - The **Schmitt Trigger (U2B - CD40106)** is used to reset the integrator when the output reaches a certain level:
     - The **input of U2B (Pin 1)** is connected to the **output of U1A** — this is correct for monitoring the integrator output.
     - The **output of U2B (Pin 2)** is connected to **RV1 (100kΩ)**, which is tied to **ground**. This sets the threshold for the Schmitt Trigger to control the reset action.
     - **Q2 (2N3904)** is used to discharge the capacitor and reset the integrator:
       - **Base of Q2** is connected to the **output of the Schmitt Trigger** via **R2 (10kΩ)** — this is correct.
       - **Collector of Q2** is connected to the **junction of C1 and U1A** — this allows Q2 to discharge the capacitor.
       - **Emitter of Q2** is connected to **ground**, which is correct.

#### **Summary of the Schematic Review**

The schematic appears to be **correct** for the **Sawtooth Core Oscillator** using the **CA3086/3046**. All key connections, including the **exponential converter**, **integrator**, and **reset mechanism**, are implemented correctly.

#### **Suggestions for Improvement**

1. **Thermal Tracking**:
   - Ensure **Q1 and Q2** are physically close together, with **thermal compound** or **shrink tubing**, to maintain consistent temperature conditions for better stability.

2. **Power Decoupling**:
   - Add **decoupling capacitors** (e.g., **100nF**) near the power supply pins of the **TL072** and **CA3086/3046** to improve stability and reduce noise.
   - Use one **decoupling capacitor for each supply rail** (±12V):
     - Place **100nF capacitors** between **+12V** and **ground**, and **-12V** and **ground**, close to each IC.
     - Adding a larger **bulk capacitor** (e.g., **10μF - 47μF electrolytic**) across the power rails may further stabilize the power supply, especially if there are transient currents or higher-frequency components present.

Using these suggestions will help improve the stability and performance of your **Sawtooth Core Oscillator** design.

### **Review of Ramp Core Schematic**

#### **General Overview**:
- The schematic appears to be designed for a ramp core oscillator with additional buffering stages using CD40106 Schmitt Trigger inverters.
- The use of a **TL072 operational amplifier** (U1A) for the integrator circuit is typical and suitable for generating a stable ramp waveform.

#### **Key Components**:
1. **Operational Amplifier (U1A - TL072)**:
   - The **TL072** is used to generate the ramp waveform.
   - **Capacitor (C1)**: The value of **22nF** sets the oscillator frequency range, along with **R1 (100kΩ)** and **RV1 (100kΩ variable resistor)**.
   - Ensure **C1** has a low tolerance for frequency stability.

2. **Transistor (Q2 - 2N3904)**:
   - **Q2** acts as a current sink, discharging the integrator capacitor to reset the ramp waveform.
   - The **base** of **Q2** should be connected to an appropriate control signal that determines the ramp frequency. This signal appears to be routed correctly in the schematic.

3. **Current Mirrors (U3A - CA3086/3046)**:
   - The **CA3086/3046** transistor array is used for the current mirror to control the ramp generation process.
   - Ensure that **Q1** and **Q2** are thermally coupled for better temperature stability, as this affects the pitch stability of the VCO.

4. **CD40106 Schmitt Trigger (U2)**:
   - **U2B** is used to shape the ramp waveform into a buffered signal for the **sawtooth output**.
   - The other stages of the **CD40106** (U2C, U2D, etc.) are available for use in buffering or further processing, which adds versatility to the circuit.

#### **Power Supply and Decoupling**:
- **CD40106 Power Supply (U2A)**: Properly decoupled using **C21 (100nF)** between **Vdd** and **GND** to suppress power supply noise.
- Make sure all ICs are properly decoupled close to the power pins to avoid oscillations and unwanted noise.

#### **Output Buffering**:
- **Sawtooth Output (OTP1)** is connected through the Schmitt trigger inverter (U2B) to **R2 (10kΩ)**, providing a low impedance buffered output.
- Verify the threshold levels of the **Schmitt trigger** to ensure it properly triggers based on the generated ramp signal levels.

#### **Recommendations**:
- The **sawtooth waveform** output seems to be well-buffered, but the Schmitt trigger's threshold voltages should be checked to ensure it doesn't distort the ramp waveform.
- For the **current mirror** transistors in **U3A (CA3086/3046)**, consider adding a small heatsink or ensuring they are mounted close together to improve thermal tracking and reduce drift.
- The **variable resistor (RV1)** allows fine-tuning of the frequency; ensure this component has a stable and smooth adjustment to prevent frequency jitter.

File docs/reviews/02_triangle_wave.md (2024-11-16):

### **Review of Triangle Wave Shaper Schematic**

Based on the schematic you provided, here’s my review:

#### **Key Points for the Triangle Wave Shaper Schematic**

1. **Sawtooth Wave Input**:
   - The **sawtooth waveform (SAW)** is correctly connected to **resistor R4 (1kΩ)**, which then goes to one of the **outer terminals of the potentiometer (RV2, 10kΩ)**.
   - This matches the intended function, where the potentiometer adjusts the ratio of the input waveform and ground.

2. **Potentiometer Wiring (RV2)**:
   - The **middle wiper** of the **potentiometer (RV2)** is connected to the **inverting input (-)** of the op-amp **U1B**.
   - The **other outer terminal** of **RV2** is connected to **ground** through **R5 (1kΩ)**, which helps in providing a stable reference for symmetry adjustment.
   - This setup correctly allows for adjusting the symmetry of the waveform by controlling the ratio between the input signal and ground.

3. **Feedback Resistor (R6)**:
   - The **feedback resistor (R6, 10kΩ)** is properly connected between the **output of U1B** (pin 7) and the **inverting input (-)** (pin 6).
   - This is essential for defining the gain and shaping the triangle wave.

4. **Non-Inverting Input (+) of U1B**:
   - The **non-inverting input (+)** (pin 5) is correctly connected to **ground**. This provides the required reference point for accurate operation of the triangle wave shaping.

5. **Power Supply for Op-Amp (U1C)**:
   - **C2 and C3 (100nF each)** are used as **decoupling capacitors** between the **±12V supplies** and **ground**. This helps stabilize the power and reduce noise.
   - **Pin 8** of **U1C** is connected to **+12V**, and **pin 4** is connected to **-12V**, which is correct for powering the TL072 op-amp.

#### **Suggestions for Improvement**

- **Add a Small Capacitor Across R6** (Optional):
  - Adding a small capacitor (e.g., **10pF to 33pF**) in parallel with **R6** could help reduce high-frequency oscillations and make the waveform smoother.

- **Range Limitation Resistors** (Optional):
  - To prevent the potentiometer from completely distorting the waveform, you could consider adding small **fixed resistors** (e.g., **1kΩ**) in series with both sides of the potentiometer. This will help in limiting the extreme positions of the potentiometer.

#### **Summary**

The schematic you provided is mostly correct for achieving an adjustable **triangle wave shaper**. The **connections to the potentiometer (RV2)**, **feedback resistor (R6)**, and the **non-inverting input** of the op-amp are all correct. This configuration should allow you to adjust the **symmetry** of the triangle wave effectively. The addition of **decoupling capacitors** is also appropriate for reducing power supply noise.

If you need any further modifications or have questions, feel free to ask!

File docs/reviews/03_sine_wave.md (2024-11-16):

### **Review of Updated Sine Wave Shaper Schematic**

Based on the updated schematic provided, here’s a detailed review of the changes:

#### **Key Observations**

1. **Triangle Wave Input (R9)**:
   - The **triangle wave input (TRI)** is correctly connected to the **inverting input (-)** of the op-amp **U4A (TL072)** through **resistor R9 (10kΩ)**.
   - This configuration is correct, as it limits the input signal amplitude to the appropriate level for shaping.

2. **Triangle Corner Shaping Potentiometer (RV4)**:
   - The **potentiometer RV4 (10kΩ)** is correctly connected in the **shaping network**.
   - The **wiper of RV4** is connected to the **junction point** of the **inverting input (-)** of **U4A** and the **diodes D1 and D2**.
   - **R8 and R7 (1kΩ each)** are now connected in series with each side of **RV4**, which helps limit the adjustment range, preventing over-clipping and distortion. This is a good improvement to ensure more control over the shaping without causing excessive signal alteration.

3. **Diode Shaping Network (D1, D2)**:
   - **Diodes D1 and D2 (1N4148)** are placed in **opposite directions**, with their junction meeting at the **inverting input (-)** of the op-amp. The **free ends** of the diodes are correctly connected to **ground**.
   - This configuration allows the diodes to act as a soft clipping element, rounding the triangle wave into a sine-like shape. The routing is correct and should yield the desired waveform transformation.
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

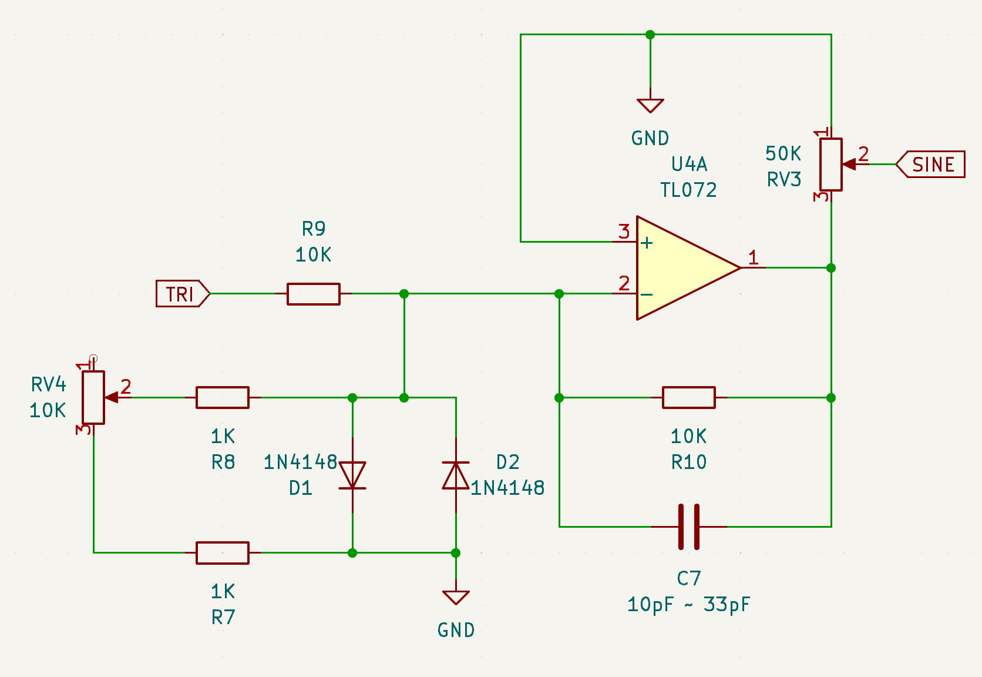
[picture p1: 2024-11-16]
docs/reviews/03_sine_wave.png

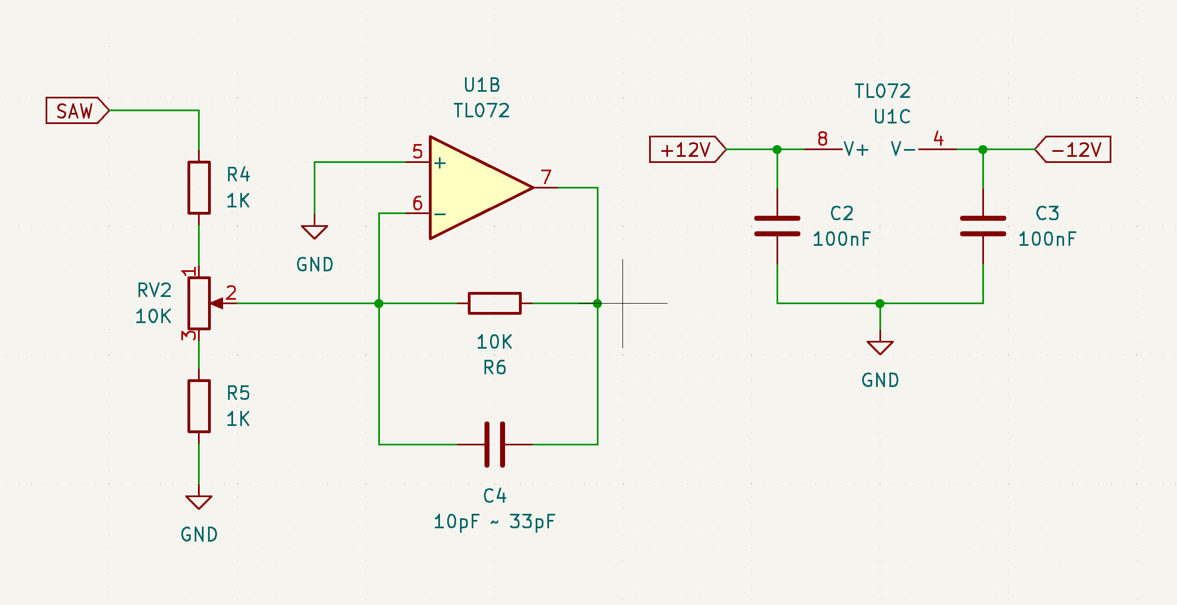
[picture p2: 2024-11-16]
docs/reviews/02_triangle_wave.png

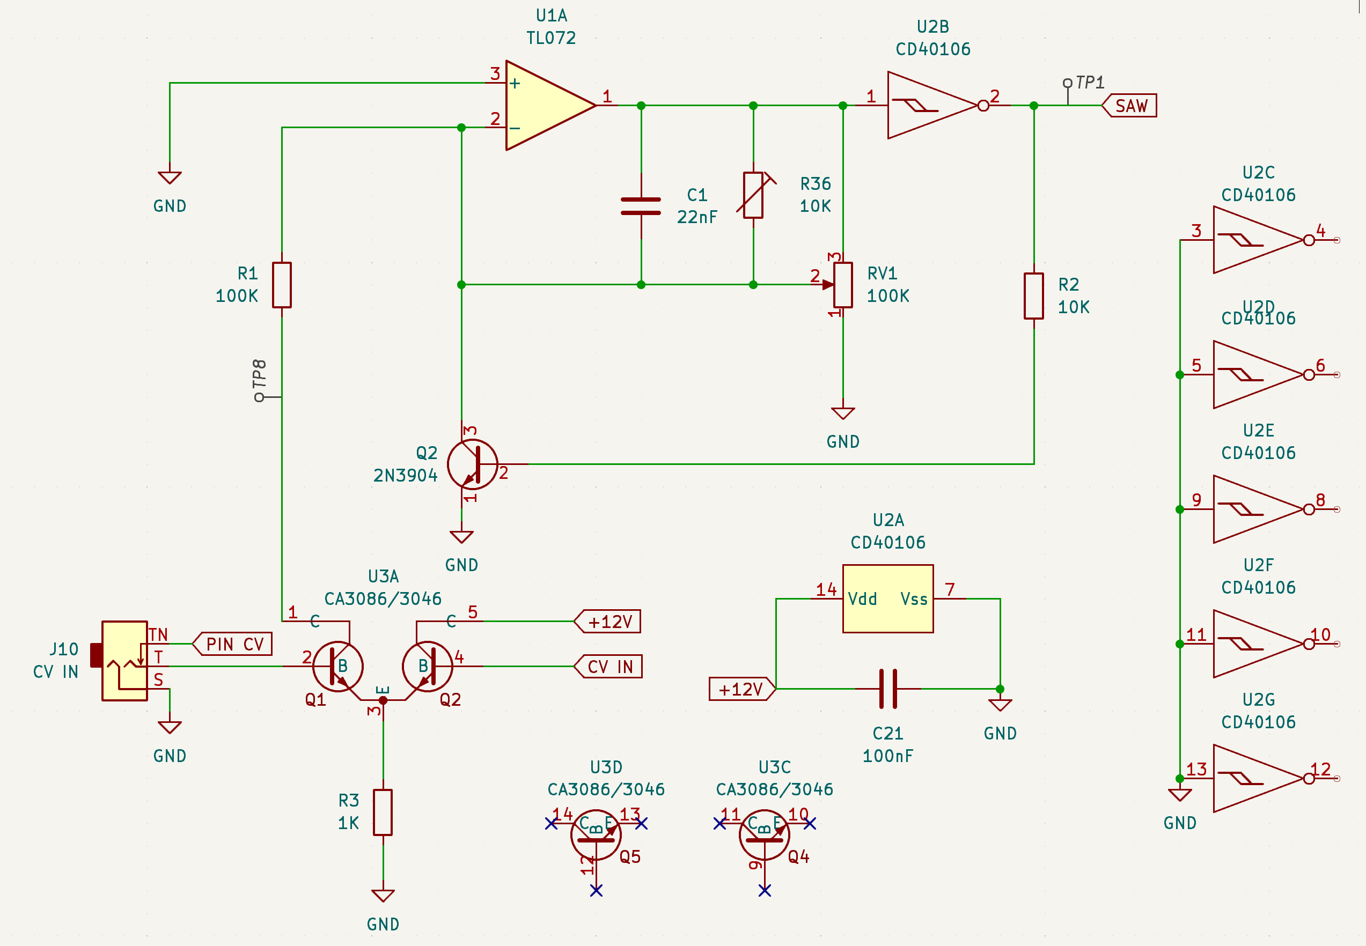
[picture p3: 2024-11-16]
docs/reviews/01_ramp_core.png

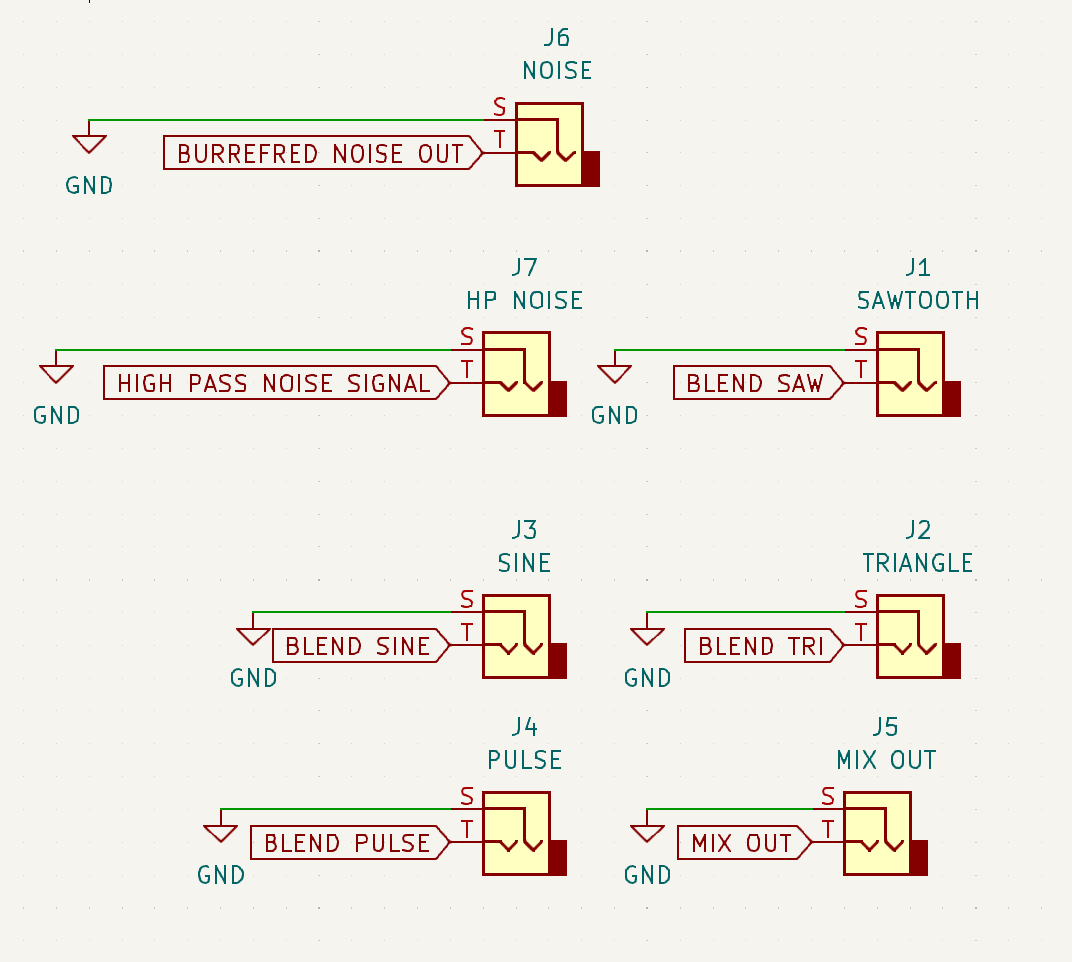
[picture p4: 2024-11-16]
docs/reviews/08_outputs.png

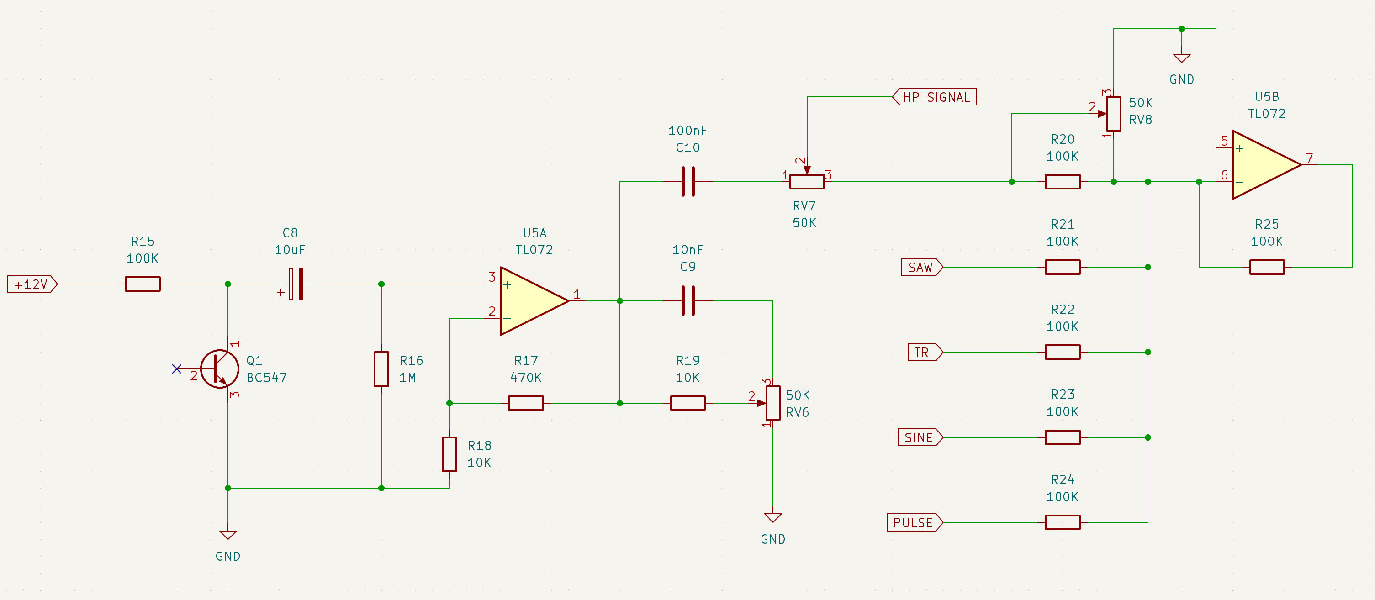
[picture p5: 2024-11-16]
docs/reviews/05_noise_generator.png

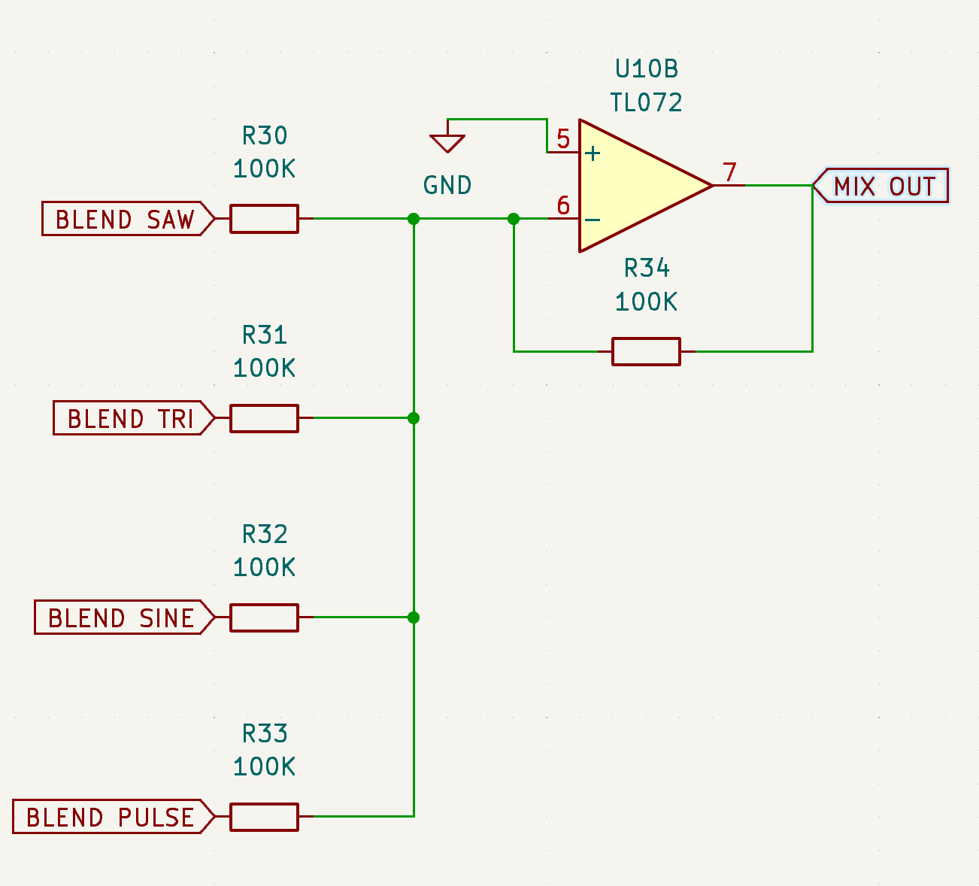
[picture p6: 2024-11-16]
docs/reviews/06_mixed_out.png

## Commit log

2024-11-16 commit project
    [modulogue_vco.kicad_pcb, modulogue_vco.kicad_sch]
2024-11-16 update pulse
    [modulogue_vco.kicad_sch]
2024-11-16 update schematic layout
    [modulogue_vco.kicad_sch]
